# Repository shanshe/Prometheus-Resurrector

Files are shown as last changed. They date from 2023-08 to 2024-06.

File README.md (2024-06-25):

# Prometheus-Resurrector (a.k.a. PrometheusX)

This is a contribution to the project <a href="http://www.e3b.de/prometheus/">Prometheus Open Source</a>. (Based on Xilinx CPLDs).

I didn't contact to anyone at E3B. As far as I know, there is only information about this project in the link above.

Why I do this? The altera version of Prometheus works perfectly, but I like VHDL/verilog and Xilinx (now AMD) FPGA/CPLDs. I have jtags for them so I wanted to play for a while...

I don't have any problem to delete this git if this bothers anyone... but I think that the little work I have done here may be useful to someone, even the original author (AFAIK Michael Boehmer mboehmer@e3b.de).

I have done the following:

 * KiCAD Schematic and PCB.

    I exported gerbers from Eagle PCB project (available at the link <a href="http://www.e3b.de/prometheus/">Prometheus Open Source</a>).
    Then gerbers were imported to a kicad Project.
    I did some modifications as I saw differences between original Prometheus schematics and the new one. Be careful because I did what I thought it was correct. Maybe there are some mistakes. Please, if you think that something is wrong, please open an Issue.

 * Corrected some little issues in the CPLDs firmware.

    The author of this project made a fantastic job, as all the work was made based on simulations only.

    1.- I have corrected the /FCS latch, because in my system, the Prometheus didn't pass autoconfig phase.

    2.- Comparing original prometheus firmware, and the new one, I saw a byteswap in two multiplexers.

    3.- There were some bit swap in the IO (found because voodoo 3 card didn't want to show video signal).

    4.- And finally, reworked the equations of the inputs in the arbiter state machine (SLOT1 X301 didn't work with PPC boards).

    Only a few little mistakes, from a huge project that was only at simulation phase... This was a great engineer job!!!

## Project State

As far as I know, with this board and firmware, you will have a Prometheus board with FireStorm firmware (DMA, PCI-PCI brigdes).

What we need now: drivers!!! For example:

<a href="https://github.com/Sakura-IT/Prometheus.git">https://github.com/Sakura-IT/Prometheus.git</a>

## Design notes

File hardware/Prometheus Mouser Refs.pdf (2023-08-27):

Designator | Footprint | Quantity | Designation | Mouser Ref
R11,R21,R10,R15,R8,R28,R31,R41,R14,R3,R4, R18,R7,R16,R23,R2,R22,R30,R20,R17,R9, R24,R6,R42,R29,R12,R13,R25,R5,R19 | R_0805_2012Metric_Pad1.20x1.40mm_HandSolder | 30 | 1k0 | 603-RT0805FRE101KL
C7,C207,C206,C6,C4,C9,C1,C209,C204,C203, C202,C201,C3,C230,C5,C208,C10,C205,C2,C8,C200,C220 | C_0402_1005Metric_Pad0.74x0.62mm_HandSolder | 22 | 100nF | 581-04025C104KAT4A
C303,C308,C311,C305,C307,C300,C302,C304,C306,C301 | CP_Radial_D6.3mm_P2.50mm | 10 | 100uF | 661-ESMG250ELL101MF
VR100 | TO-252-2 | 1 | AP1117-ADJ | 511-LD1117ADT33-TR
R1 | R_0402_1005Metric_Pad0.72x0.64mm_HandSolder | 1 | 4k7 | 603-RT0402FRE074K7L
X303,X301,X300,X302 | PCI | 4 | Bus_PCI_32bit_5V | 571-5145154-8
R300 | R_1206_3216Metric_Pad1.30x1.75mm_HandSolder | 1 | 2k0 | 708-RMCF1206FT2K00
R43,R44,R46,R45 | R_0805_2012Metric_Pad1.20x1.40mm_HandSolder | 4 | 10k0 | 603-RC0805FR-0710KL
RA202 | R_Array_Convex_4x0612 | 1 | R_Pack04 | 652-CAY16-102J4LF
Q203 | Oscillator_SMD_Fordahl_DFAS15-4Pin_5.0x3.2mm | 1 | 33MHz | 815-SFL133000MHZLRST
R209 | R_0805_2012Metric_Pad1.20x1.40mm_HandSolder | 1 | FerriteBead_Small | 791-WLBD2012HCU600TH
VR300 | DCDC | 1 | ~ | 595-PTH12000WAD
R26 | R_0805_2012Metric_Pad1.20x1.40mm_HandSolder | 1 | 3k3 | 603-RT0805FRE133K3L
C309,C310 | C_1206_3216Metric_Pad1.33x1.80mm_HandSolder | 2 | 100nF | C1206C104K5RAC7210
CON300 | TE-350211-MATE-N-LCK-RightAngle | 1 | Conn_01x04_Pin | 571-16417371
C12,C11 | C_1210_3225Metric_Pad1.33x2.70mm_HandSolder | 2 | 10uF Tantalum | 581-TAJB106K025RNJ
IC201H1,IC200L1 | TQFP-144_20x20mm_P0.5mm | 2 | XC95144XL-TQ144 | 217-5144XL-10TQG144C
R27 | R_0805_2012Metric_Pad1.20x1.40mm_HandSolder | 1 | 4k7 | RC0805FR-074K7L
R202 | R_0805_2012Metric_Pad1.20x1.40mm_HandSolder | 1 | 15R | RC0805FR-0715RL

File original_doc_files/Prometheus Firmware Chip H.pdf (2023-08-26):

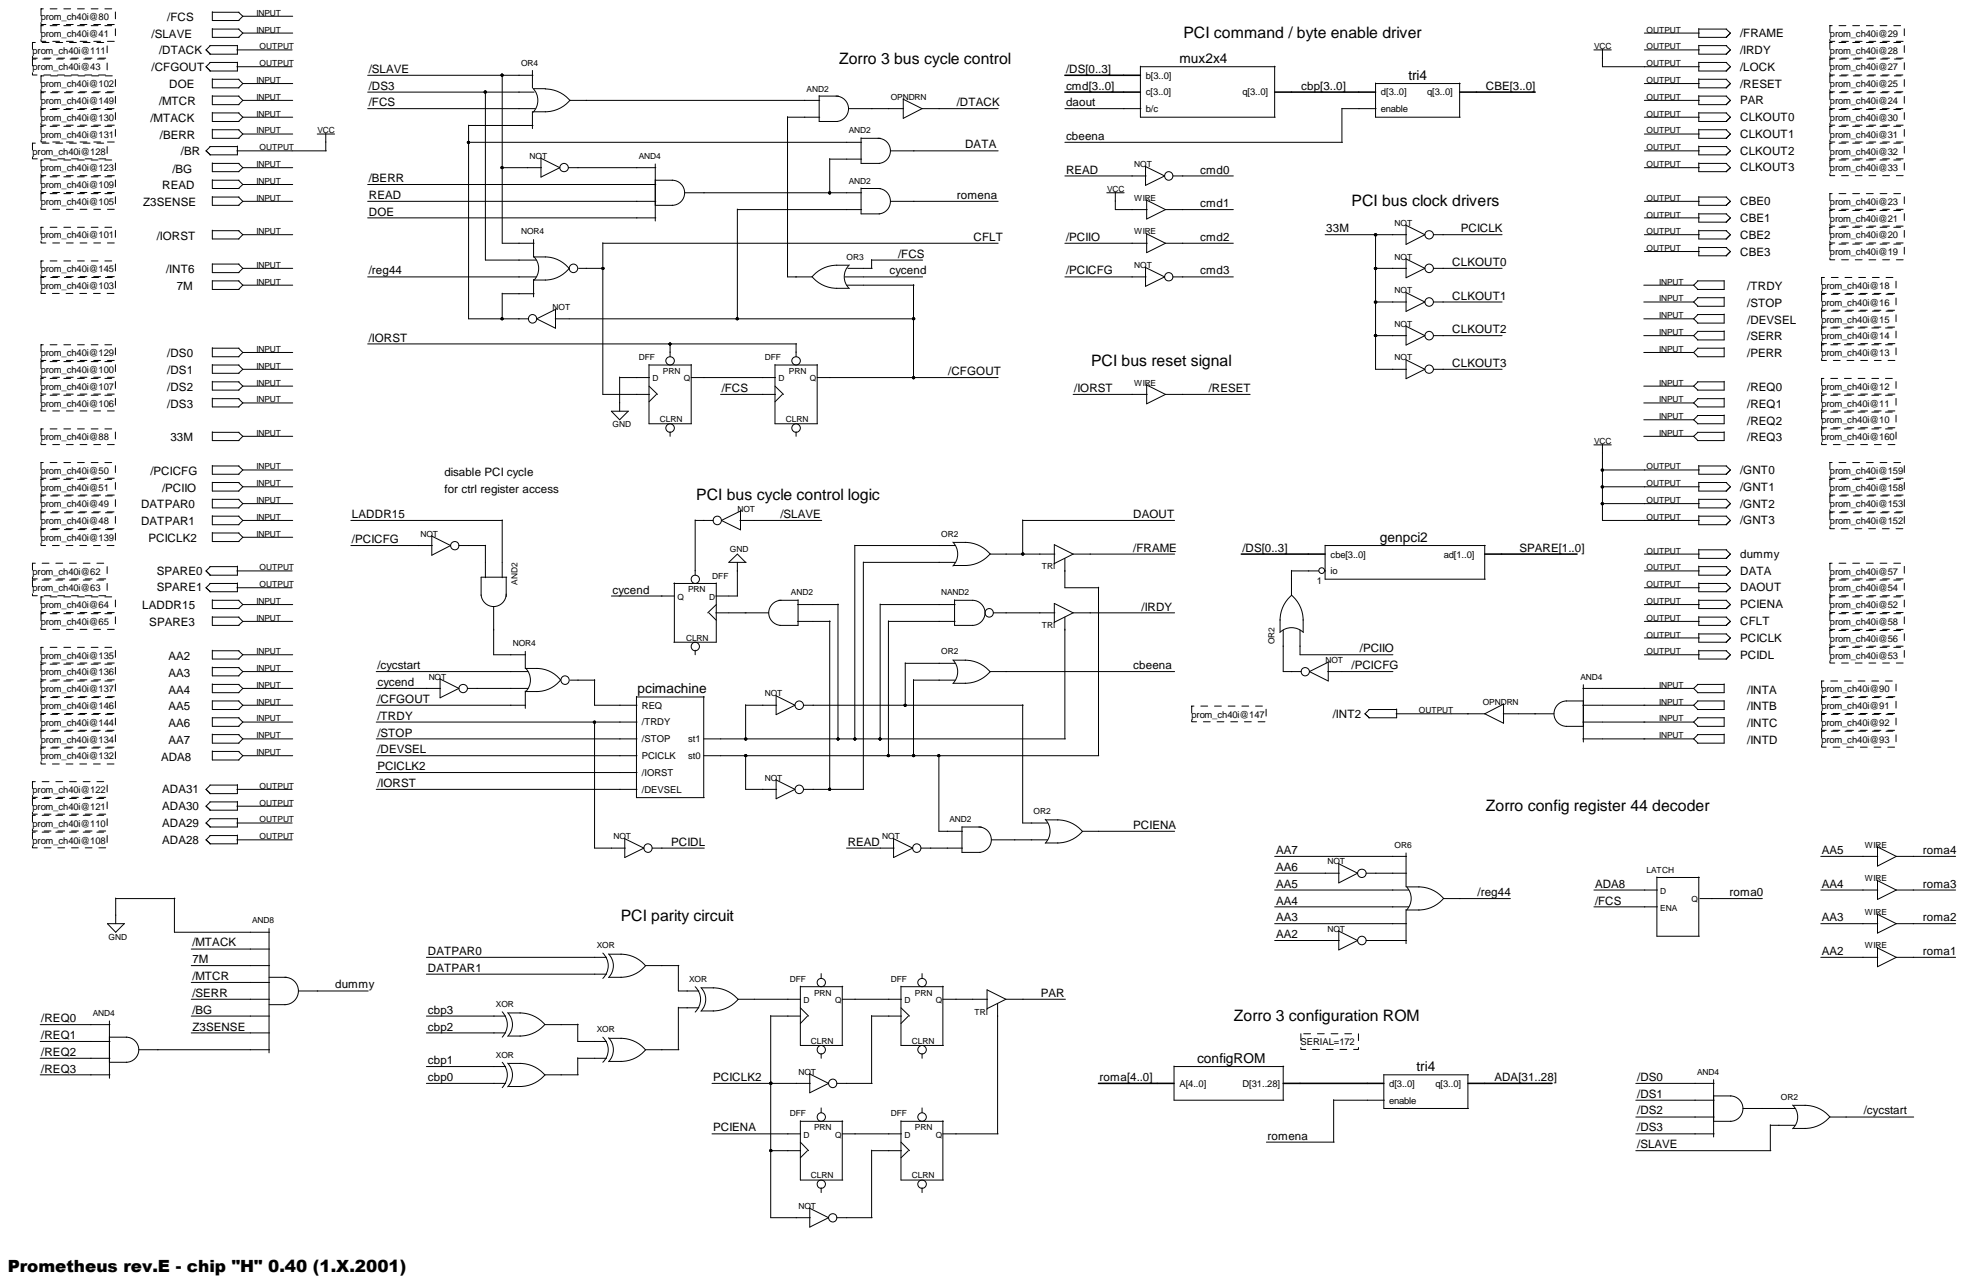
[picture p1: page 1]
/REQ1; prom_ch40i@11 INPUT; /INTD; prom_ch40i@93 INPUT; /INTC; prom_ch40i@92 INPUT; /INTB; prom_ch40i@91 INPUT; /INTA; prom_ch40i@90 INPUT; prom_ch40i@130; /MTACK; INPUT; prom_ch40i@49; DATPAR0; prom_ch40i@132; ADA8; prom_ch40i@134; prom_ch40i@144; prom_ch40i@146; prom_ch40i@137; prom_ch40i@136; prom_ch40i@135; prom_ch40i@65; SPARE3; prom_ch40i@64; LADDR15; prom_ch40i@139; PCICLK2; prom_ch40i@102; DOE; prom_ch40i@48; DATPAR1; prom_ch40i@51; /PCIIO; prom_ch40i@50; /PCICFG; prom_ch40i@41; /SLAVE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

PCI command / byte enable driver
mux2x4

Zorro 3 bus cycle control

PCI bus clock drivers

PCI bus reset signal

disable PCI cycle
for ctrl register access

PCI bus cycle control logic

Zorro config register 44 decoder

PCI parity circuit

Zorro 3 configuration ROM

Prometheus rev.E - chip "H" 0.40 (1.X.2001)

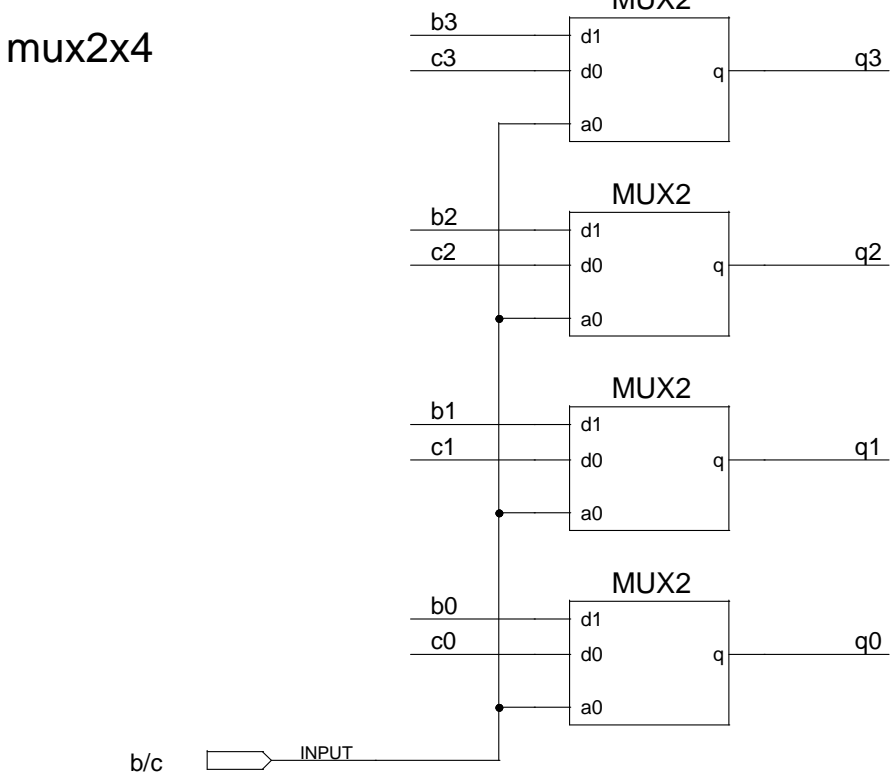
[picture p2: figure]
mux2x4; MUX2; INPUT

### MUX2

c[3..0] | INPUT
b[3..0] | INPUT | q[3..0] OUTPUT

b[3..0]

c[3..0]

q[3..0]

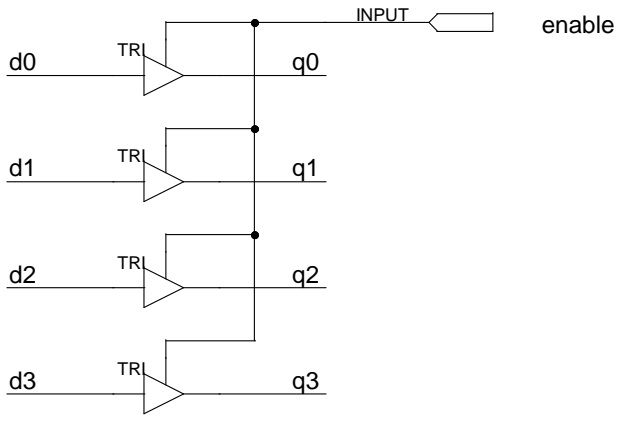
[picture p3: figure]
TRI; enable INPUT

# tri4

d[3..0] | INPUT
q[3..0] d[3..0] | q[3..0] | OUTPUT

SUBDESIGN genpci2
(
cbe[3..0], io : INPUT;
ad[1..0] : OUTPUT;
)

BEGIN
TABLE
cbe[3..0], io => ad1, ad0;
B"0000" , 1 => | 0, | 0;
B"0001" , 1 => | 0, | 1;
B"0010" , 1 => | 0, | 0;
B"0011" , 1 => | 1, | 0;
B"0100" , 1 => | 0, | 0;
B"0101" , 1 => | 0, | 1;
B"0110" , 1 => | 0, | 0;
B"0111" , 1 => | 1, | 1;
B"1000" , 1 => | 0, | 0;
B"1001" , 1 => | 0, | 1;
B"1010" , 1 => | 0, | 0;
B"1011" , 1 => | 1, | 0;
B"1100" , 1 => | 0, | 0;
B"1101" , 1 => | 0, | 1;
B"1110" , 1 => | 0, | 0;
B"1111" , 1 => | 0, | 0;
B"xxxx" , 0 => | 0, | 0;
END TABLE;
END;

### pcimachine2

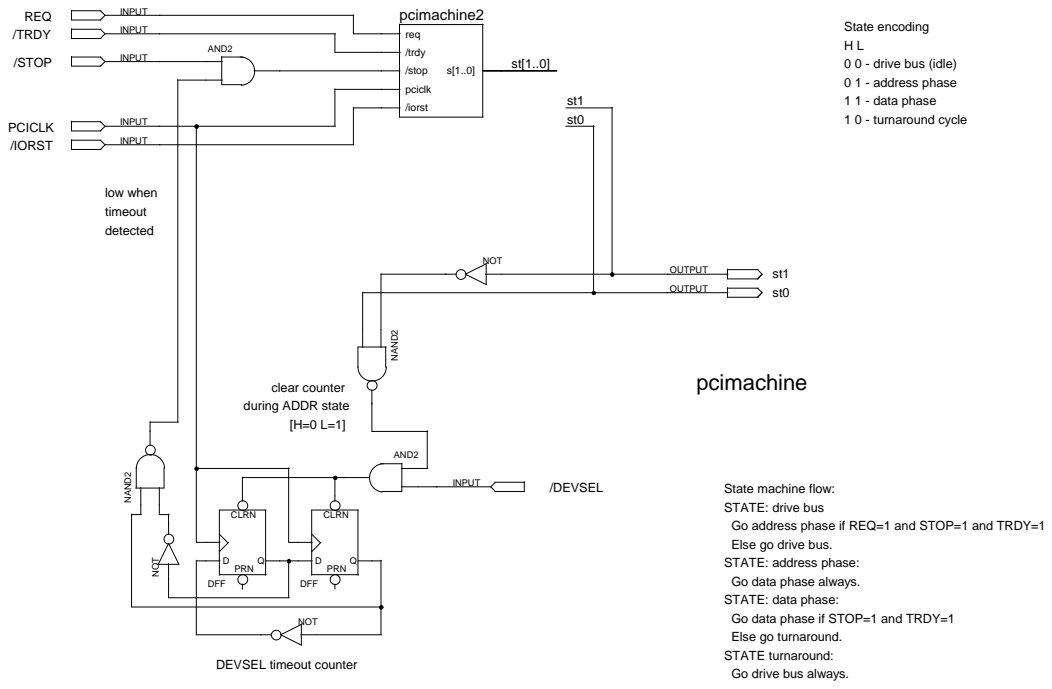
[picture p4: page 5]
detected; low when timeout; pcimachine; DFF; CLRN; PRN; PCICLK; INPUT; /IORST; /DEVSEL INPUT; /STOP; /TRDY; REQ; st0 OUTPUT; st1 OUTPUT; NOT; AND2; NAND2; req /trdy /stop pciclk /iorst

State encoding
0 0 - drive bus (idle)
0 1 - address phase
1 1 - data phase
1 0 - turnaround cycle

clear counter
during ADDR state

State machine flow:
STATE: drive bus
Go address phase if REQ=1 and STOP=1 and TRDY=1
Else go drive bus.
STATE: address phase:
Go data phase always.
STATE: data phase:
Go data phase if STOP=1 and TRDY=1
Else go turnaround.
STATE turnaround:
Go drive bus always.

DEVSEL timeout counter

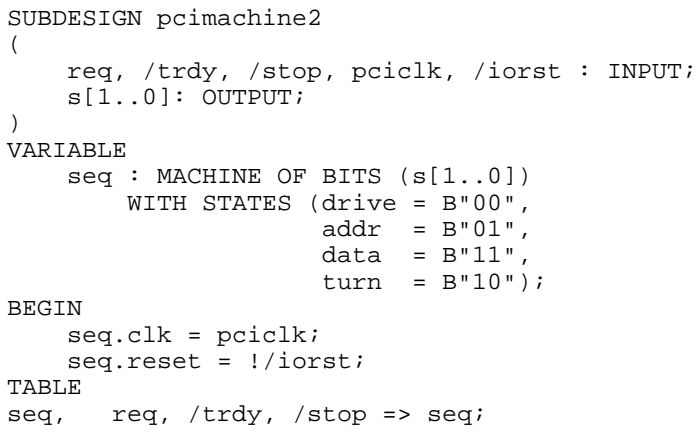
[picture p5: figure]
SUBDESIGN pcimachine2 (; s[1..0]: OUTPUT;; ) VARIABLE seq : MACHINE OF BITS (s[1..0]) WITH STATES (drive = B"00", addr = B"01", data = B"11", turn = B"10");; BEGIN seq.clk = pciclk; seq.reset = !/iorst; TABLE; seq,; req, /trdy, /stop => seq;

req, /trdy, /stop, pciclk, /iorst : INPUT;

drive, | 0, | X, | X => drive;
drive, | 1, | 0, | X => drive;
drive, | 1, | 1, | 0 => drive;
drive, | 1, | 1, | 1 => addr;
addr, | X, | X, | X => data;
data, | X, | 0, | X => turn;
data, | X, | 1, | 0 => turn;
data, | X, | 1, | 1 => data;
turn, | X, | X, | X => drive;
END TABLE;
END;

PARAMETERS
(
SERIAL
);

CONSTANT S0R = ((SERIAL & H"F0000000") DIV H"10000000") XOR H"F"; CONSTANT S1R = ((SERIAL & H"0F000000") DIV H"01000000") XOR H"F"; CONSTANT S2R = ((SERIAL & H"00F00000") DIV H"00100000") XOR H"F"; CONSTANT S3R = ((SERIAL & H"000F0000") DIV H"00010000") XOR H"F"; CONSTANT S4R = ((SERIAL & H"0000F000") DIV H"00001000") XOR H"F"; CONSTANT S5R = ((SERIAL & H"00000F00") DIV H"00000100") XOR H"F";
CONSTANT S6R = ((SERIAL & H"000000F0") DIV H"00000010") XOR H"F";
CONSTANT S7R = ((SERIAL & H"0000000F") DIV H"00000001") XOR H"F";

CONSTANT MANUFACTURER = H"AD47"; % Amiga Inc. hardware developer number %

CONSTANT M0R = ((MANUFACTURER & H"F000") DIV H"1000") XOR H"F";
CONSTANT M1R = ((MANUFACTURER & H"0F00") DIV H"0100") XOR H"F";
CONSTANT M2R = ((MANUFACTURER & H"00F0") DIV H"0010") XOR H"F";
CONSTANT M3R = ((MANUFACTURER & H"000F") DIV H"0001") XOR H"F";
CONSTANT DEVTYPE = 1; | % device type %

CONSTANT D0R = ((DEVTYPE & H"F0") DIV H"10") XOR H"F";
CONSTANT D1R = ((DEVTYPE & H"0F") DIV H"01") XOR H"F";
CONSTANT ROMVEC = H"0000"; | % ROM offset (currently unused) %

CONSTANT R0R = ((ROMVEC & H"F000") DIV H"1000") XOR H"F";
CONSTANT R1R = ((ROMVEC & H"0F00") DIV H"0100") XOR H"F";
CONSTANT R2R = ((ROMVEC & H"00F0") DIV H"0010") XOR H"F";
CONSTANT R3R = ((ROMVEC & H"000F") DIV H"0001") XOR H"F";

SUBDESIGN ConfigROM
(
A[4..0] : INPUT;
D[31..28] : OUTPUT;
)
BEGIN
CASE A[] IS
WHEN 0 => D[] = B"1000"; % $000 - Z3 type, no autolink RAM, no boot ROM %
WHEN 1 => D[] = B"0101"; % $101 - single dev. board, 512 MB size | %

% device number (see constant above), register $004 %

WHEN 2 => D[] = D0R;
WHEN 3 => D[] = D1R;
WHEN 4 => D[] = B"1100"; % $008 - I/O dev., not shutupable, Z3 size | %
WHEN 5 => D[] = B"1111"; % $108 - Logical size matches physical size | %

WHEN 6 => D[] = B"1111"; % $00C - Reserved | %
WHEN 7 => D[] = B"1111"; % $10C - Reserved | %

% manufacturer number (see constant above), registers $010 and $014 %

WHEN 8 => D[] = M0R;
WHEN 9 => D[] = M1R;
WHEN 10 => D[] = M2R;
WHEN 11 => D[] = M3R;

% serial number (see constant above), registers $018 to $024 %

WHEN 12 => D[] = S0R;
WHEN 13 => D[] = S1R;
WHEN 14 => D[] = S2R;
WHEN 15 => D[] = S3R;
WHEN 16 => D[] = S4R;
WHEN 17 => D[] = S5R;
WHEN 18 => D[] = S6R;
WHEN 19 => D[] = S7R;

% ROM vector (see constant above), registers $028 and $02C %

WHEN 20 => D[] = R0R;
WHEN 21 => D[] = R1R;
WHEN 22 => D[] = R2R;
WHEN 23 => D[] = R3R;

% others reserved %

WHEN OTHERS => D[] = B"1111"; END CASE;
END;

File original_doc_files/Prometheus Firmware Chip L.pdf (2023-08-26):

Zorro 3 address latch | Zorro 3 address gate (512 MB) | Address decoder | PCI space decoder

## latch8

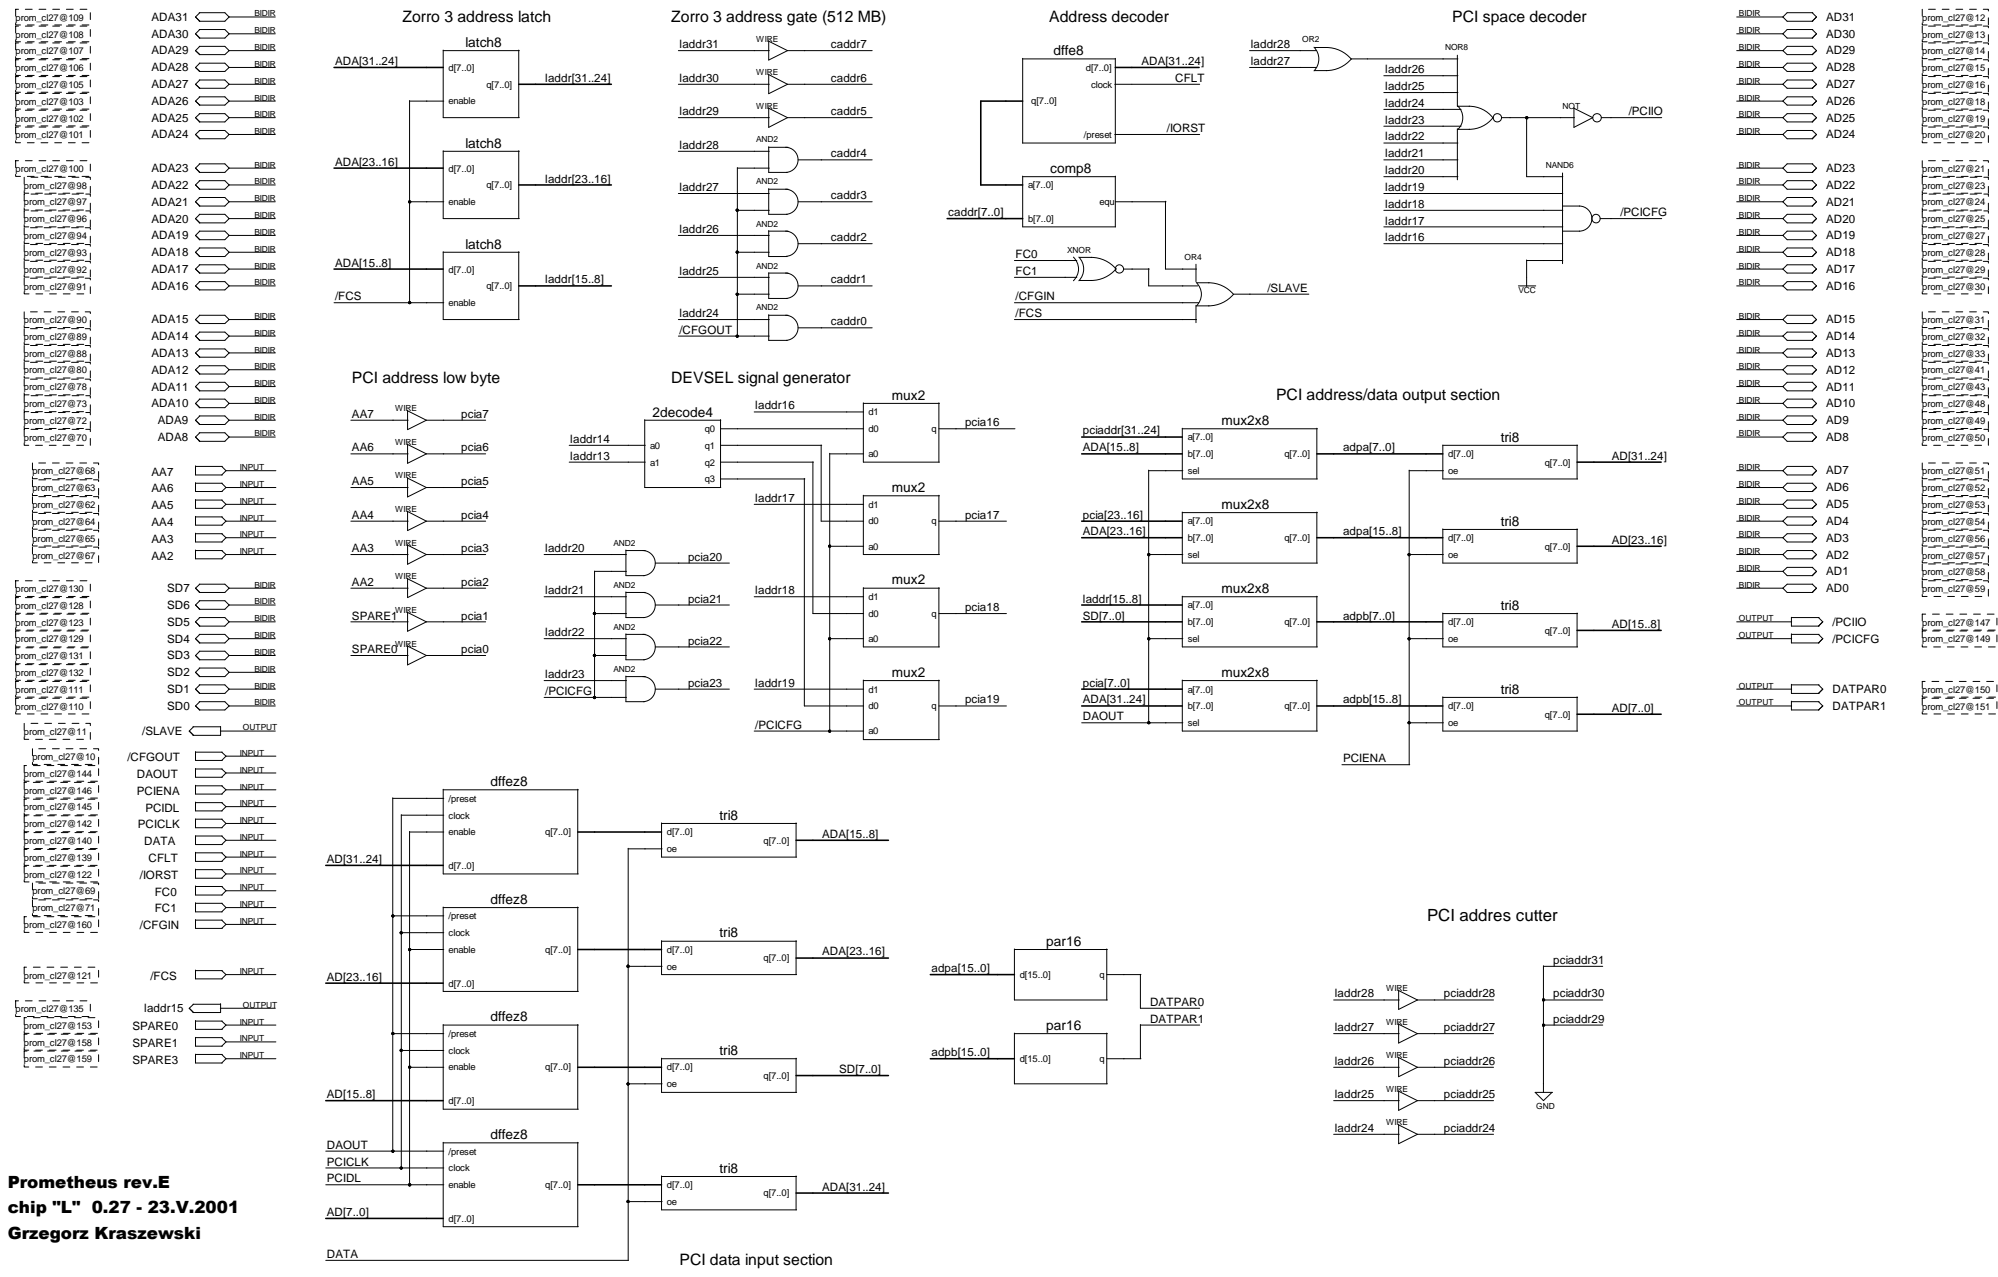
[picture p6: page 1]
PCI address low byte; DEVSEL signal generator; Prometheus rev.E; chip "L" 0.27 - 23.V.2001; Grzegorz Kraszewski; prom_cl27@109; ADA31; BIDIR; prom_cl27@59 BIDIR; prom_cl27@57 BIDIR; prom_cl27@58 BIDIR; prom_cl27@56 BIDIR; prom_cl27@54 BIDIR; prom_cl27@52 BIDIR; prom_cl27@53 BIDIR; prom_cl27@51 BIDIR; prom_cl27@49 BIDIR; prom_cl27@50 BIDIR; prom_cl27@43 BIDIR; prom_cl27@48 BIDIR; prom_cl27@33 BIDIR; prom_cl27@41 BIDIR; prom_cl27@31 BIDIR; prom_cl27@32 BIDIR; prom_cl27@30 BIDIR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

PCI address/data output section

PCI addres cutter

PCI data input section

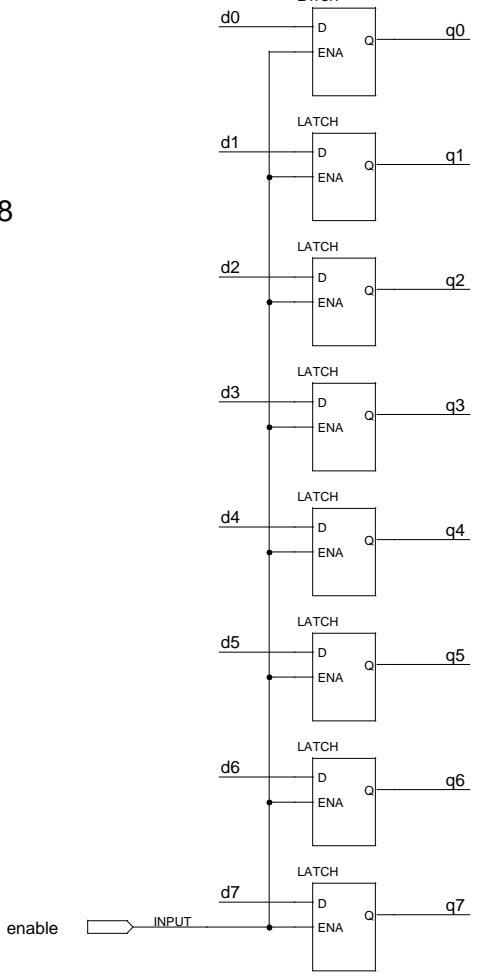
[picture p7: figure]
ENA; LATCH; enable; INPUT

# latch8

## LATCH

d[7..0] | INPUT | q[7..0] OUTPUT
d[7..0] | q[7..0]

# dffe8

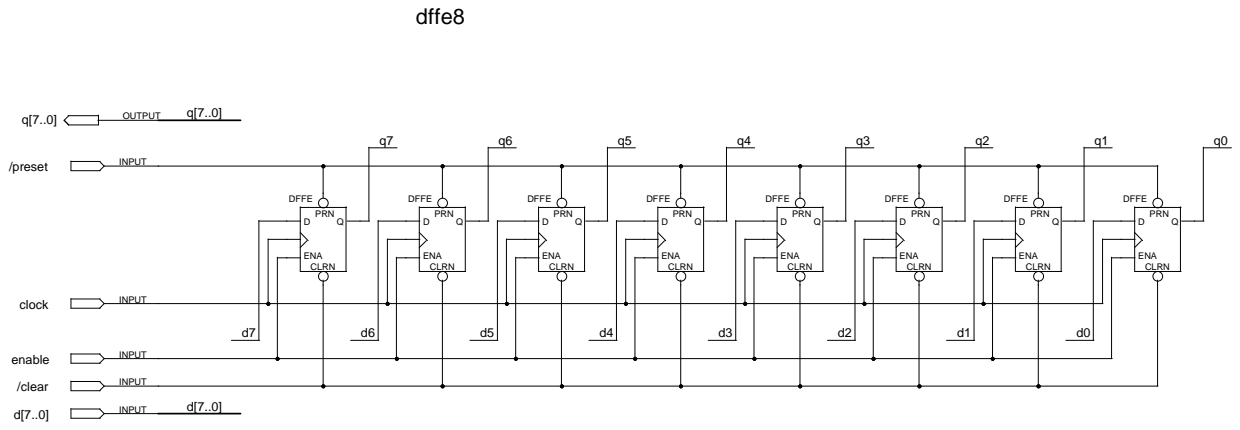
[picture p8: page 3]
enable; INPUT; /clear; clock; /preset; OUTPUT; DFFE; ENA CLRN; PRN

# comp8

# XOR

a[7..0] | INPUT
b[7..0] | INPUT

a7

a[7..0]

b[7..0]

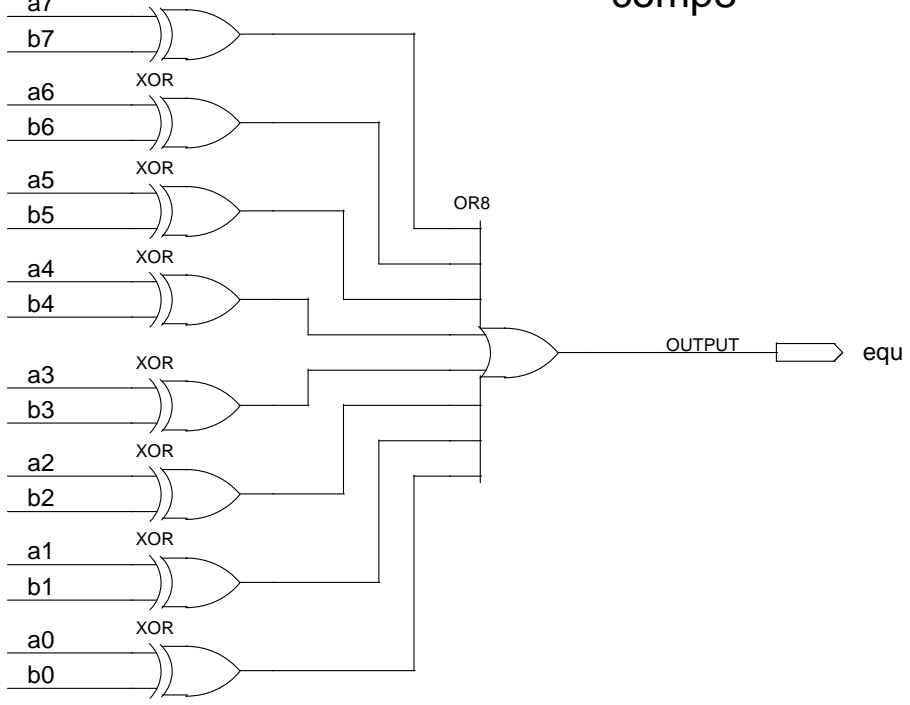
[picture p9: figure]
XOR; equ OUTPUT

# 2decode4

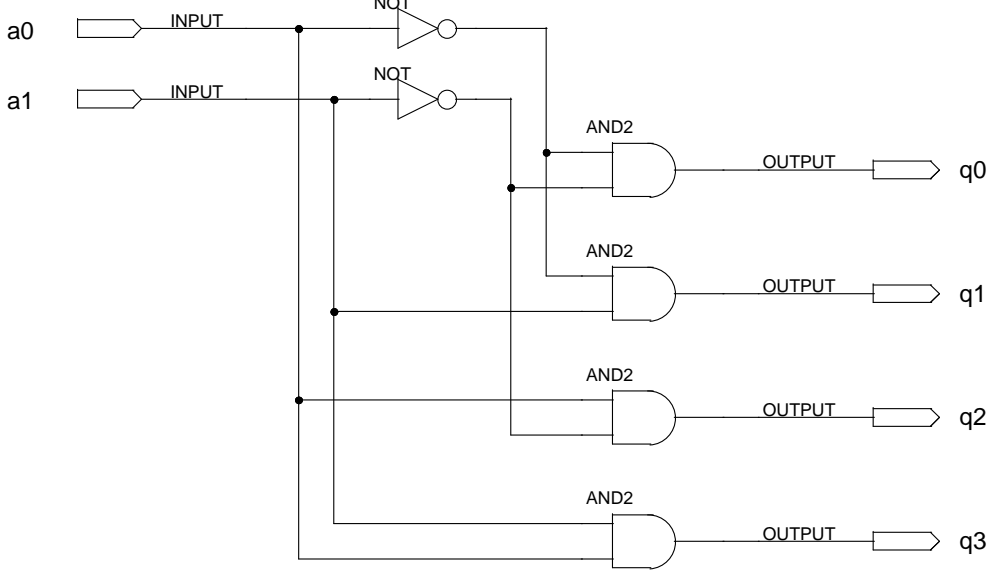
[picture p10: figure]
AND2; NOT; INPUT; q0 OUTPUT; q3 OUTPUT; q2 OUTPUT; q1 OUTPUT

# NOT

# mux2

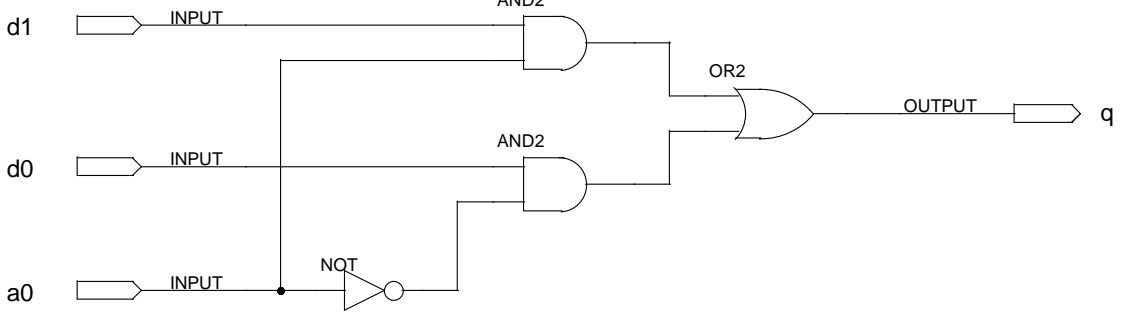
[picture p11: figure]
AND2; NOT; INPUT; q OUTPUT

# AND2

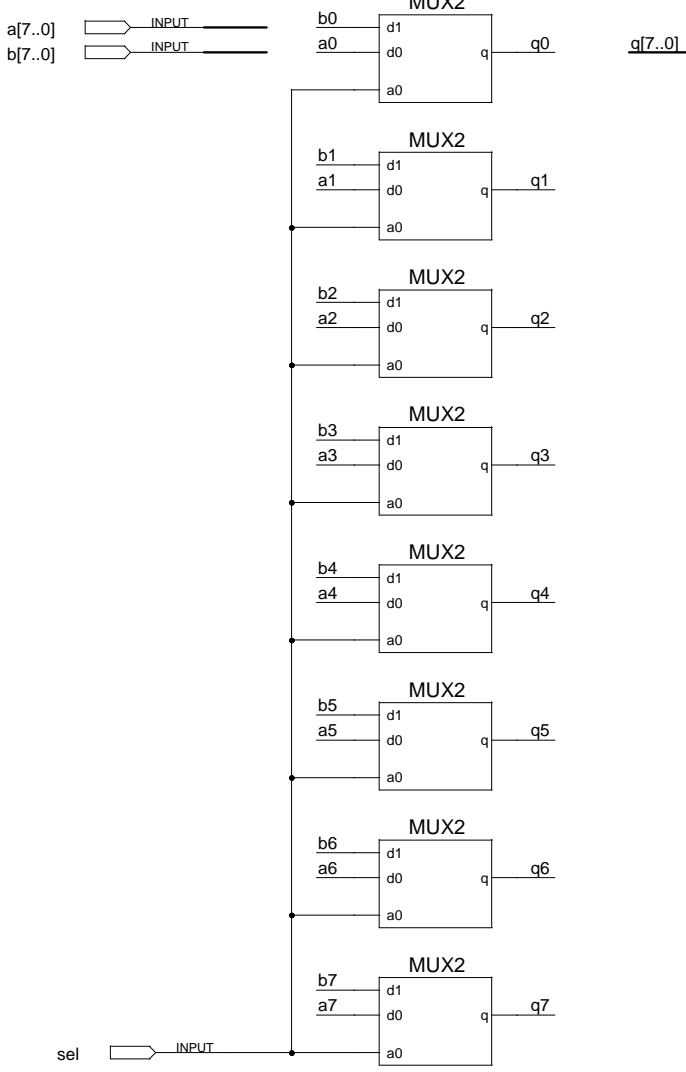
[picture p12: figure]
MUX2; INPUT; sel

# mux2x8

# MUX2

# q[7..0] OUTPUT

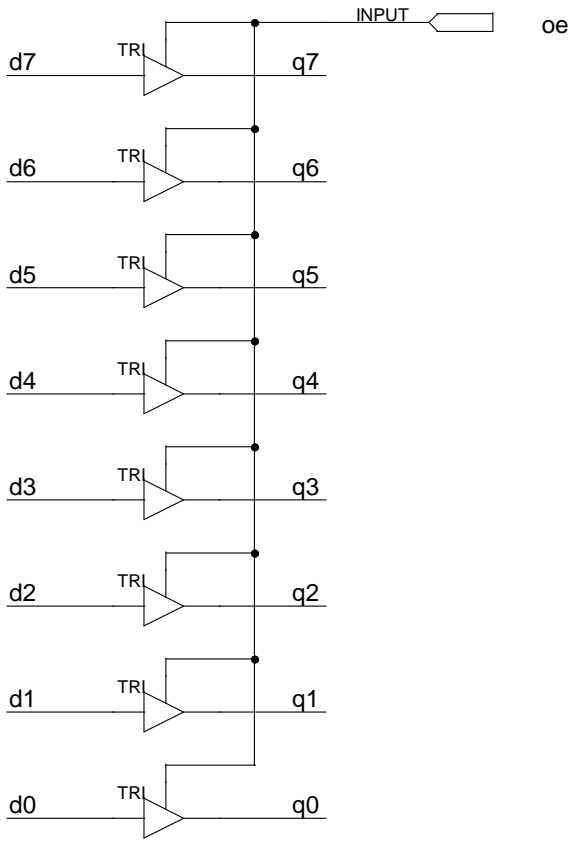
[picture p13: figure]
TRI; oe INPUT

# tri8

d[7..0] | INPUT
q[7..0] d[7..0] | q[7..0] | OUTPUT

# dffez8

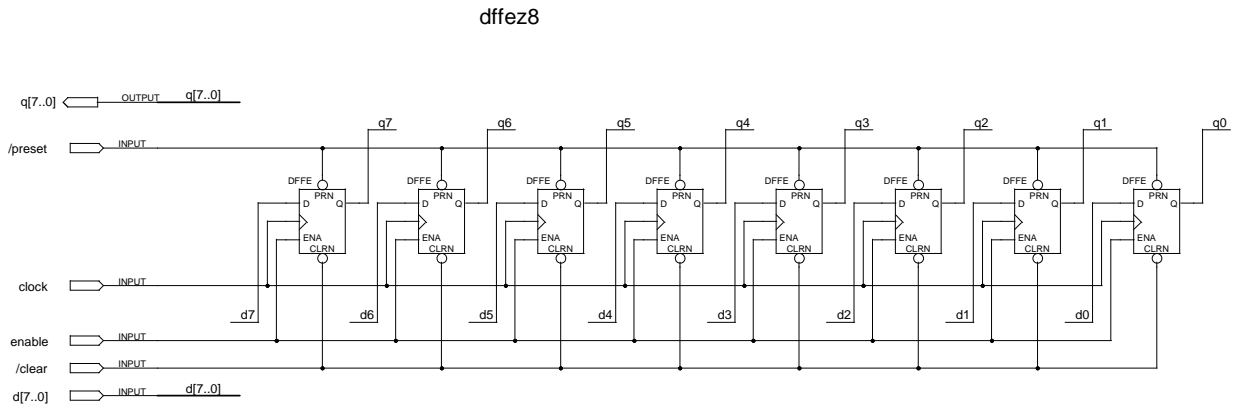
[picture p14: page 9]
INPUT; /clear; enable; clock; /preset; OUTPUT; DFFE; ENA CLRN; PRN

# par16

# XOR

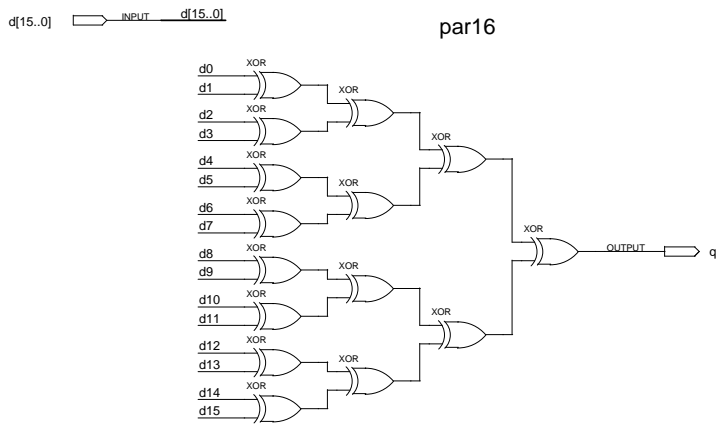
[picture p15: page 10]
XOR; q OUTPUT; INPUT

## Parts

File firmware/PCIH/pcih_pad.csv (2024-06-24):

Release 8.1i - Fit P.20131013
Copyright(c) 1995-2003 Xilinx Inc. All rights reserved
6-24-2024 8:03PM
NOTE: This file is designed to be imported into a spreadsheet program
such as Microsoft Excel for viewing | printing and sorting. The comma ' | '
character is used as the data field separator.
This file is also designed to support parsing.
Input file: pcih.ngd
output file: pcih_pad.csv
Part type: xc95144xl
Speed grade: -10
Package: tq144
Pinout by Pin Number:
----- | ----- | ----- | ----- | ----- | ----- | ----- | ----- | ----- | -----
Pin Number | Signal Name | Pin Usage | Pin Name | Direction | IO Standard | IO Bank Number | {blank} | Slew Rate | Termination | {blank} | Voltage | Constraint
P1 | VCC |  | VCCIO
P2 | TIE |  | I/O/GTS3
P3 | TIE |  | I/O/GTS4
P4 | TIE |  | I/O
P5 | TIE |  | I/O/GTS1
P6 | TIE |  | I/O/GTS2
P7 | TIE |  | I/O
P8 | VCC |  | VCCINT
P9 | Z_AA<5> | I | I/O | INPUT
P10 | TIE |  | I/O
P11 | Z_AA<6> | I | I/O | INPUT
P12 | Z_AA<4> | I | I/O | INPUT
P13 | Z_AA<3> | I | I/O | INPUT
P14 | TIE |  | I/O
P15 | Z_AA<2> | I | I/O | INPUT
P16 | Z_AA<7> | I | I/O | INPUT
P17 | TIE |  | I/O
P18 | GND |  | GND
P19 | TIE |  | I/O
P20 | Z_NBERR | I | I/O | INPUT
P21 | Z_READ | I | I/O | INPUT
P22 | Z_ADA<29> | O | I/O | OUTPUT
P23 | Z_NDTACK | O | I/O | OUTPUT
P24 | Z_ADA<30> | I/O | I/O | BIDIR
P25 | Z_ADA<31> | I/O | I/O | BIDIR
P26 | Z_NDS<0> | I | I/O | INPUT
P27 | Z_ADA<28> | O | I/O | OUTPUT
P28 | Z_NDS<2> | I | I/O | INPUT
P29 | GND |  | GND
P30 | I_33M | I | I/O/GCK1 | INPUT
P31 | I_PCICLK | O | I/O | OUTPUT
P32 | I_PCICLK2 | GCK | I/O/GCK2
P33 | Z_NDS<3> | I | I/O | INPUT
P34 | TIE |  | I/O
P35 | Z_DOE | I | I/O | INPUT
P36 | GND |  | GND
P37 | VCC |  | VCCIO
P38 | Z_NFCS | GCK/I | I/O/GCK3
P39 | Z_NDS<1> | I | I/O | INPUT
P40 | I_ACC<1> | I | I/O | INPUT
P41 | I_ACC<0> | I | I/O | INPUT
P42 | VCC |  | VCCINT
P43 | I_DATPAR<1> | I | I/O | INPUT
P44 | I_DATPAR<0> | I | I/O | INPUT
P45 | I_DAOUT | O | I/O | OUTPUT
P46 | I_PCIENA | O | I/O | OUTPUT
P47 | GND |  | GND
P48 | I_PCIDL | O | I/O | OUTPUT
P49 | I_DATA | O | I/O | OUTPUT
P50 | I_CFLT | O | I/O | OUTPUT
P51 | I_PLA<1> | O | I/O | OUTPUT
P52 | I_PLA<0> | O | I/O | OUTPUT
P53 | I_ZLA | I | I/O | INPUT
P54 | I_ZMA | I | I/O | INPUT
P55 | VCC |  | VCCIO
P56 | TIE |  | I/O
P57 | TIE |  | I/O
P58 | TIE |  | I/O
P59 | TIE |  | I/O
P60 | TIE |  | I/O
P61 | TIE |  | I/O
P62 | GND |  | GND
P63 | TDI |  | TDI
P64 | TIE |  | I/O
P65 | TMS |  | TMS
P66 | TIE |  | I/O
P67 | TCK |  | TCK
P68 | I_NINT6 | O | I/O | OUTPUT
P69 | I_NINT2 | O | I/O | OUTPUT
P70 | Z_NCFGOUT | O | I/O | OUTPUT
P71 | Z_NSLAVE | I | I/O | INPUT
P72 | GND |  | GND
P73 | VCC |  | VCCIO
P74 | P_CBE<1> | I/O | I/O | BIDIR
P75 | TIE |  | I/O
P76 | TIE |  | I/O
P77 | P_NLOCK | O | I/O | OUTPUT
P78 | P_NDEVSEL | I | I/O | INPUT
P79 | P_NIRDY | I/O | I/O | BIDIR
P80 | P_CBE<2> | I/O | I/O | BIDIR
P81 | P_CBE<3> | I/O | I/O | BIDIR
P82 | P_NREQ<0> | I | I/O | INPUT
P83 | P_NGNT<1> | O | I/O | OUTPUT
P84 | VCC |  | VCCINT
P85 | P_NREQ<1> | I | I/O | INPUT
P86 | P_NGNT<0> | O | I/O | OUTPUT
P87 | P_CLKOUT<0> | O | I/O | OUTPUT
P88 | P_CLKOUT<1> | O | I/O | OUTPUT
P89 | GND |  | GND
P90 | GND |  | GND
P91 | P_NINTC | I | I/O | INPUT
P92 | P_NINTD | I | I/O | INPUT
P93 | P_NINTA | I | I/O | INPUT
P94 | P_NINTB | I | I/O | INPUT
P95 | P_NRESET | O | I/O | OUTPUT
P96 | P_CLKOUT<3> | O | I/O | OUTPUT
P97 | P_NGNT<3> | O | I/O | OUTPUT
P98 | P_NREQ<3> | I | I/O | INPUT
P99 | GND |  | GND
P100 | P_NGNT<2> | O | I/O | OUTPUT
P101 | P_CLKOUT<2> | O | I/O | OUTPUT
P102 | P_NREQ<2> | I | I/O | INPUT
P103 | P_NFRAME | I/O | I/O | BIDIR
P104 | P_NTRDY | I | I/O | INPUT
P105 | P_NSTOP | I | I/O | INPUT
P106 | P_PAR | O | I/O | OUTPUT
P107 | P_CBE<0> | I/O | I/O | BIDIR
P108 | GND |  | GND
P109 | VCC |  | VCCIO
P110 | TIE |  | I/O
P111 | TIE |  | I/O
P112 | TIE |  | I/O
P113 | TIE |  | I/O
P114 | GND |  | GND
P115 | TIE |  | I/O
P116 | DEBUG<0> | O | I/O | OUTPUT
P117 | DEBUG<1> | O | I/O | OUTPUT
P118 | DEBUG<2> | O | I/O | OUTPUT
P119 | DEBUG<3> | O | I/O | OUTPUT
P120 | DEBUG<4> | O | I/O | OUTPUT
P121 | DEBUG<5> | O | I/O | OUTPUT
P122 | TDO |  | TDO
P123 | GND |  | GND
P124 | TIE |  | I/O
P125 | TIE |  | I/O
P126 | TIE |  | I/O
P127 | VCC |  | VCCIO
P128 | DEBUG<6> | O | I/O | OUTPUT
P129 | DEBUG<7> | O | I/O | OUTPUT
P130 | DEBUG<8> | O | I/O | OUTPUT
P131 | DEBUG<9> | O | I/O | OUTPUT
P132 | DEBUG<10> | O | I/O | OUTPUT
P133 | DEBUG<11> | O | I/O | OUTPUT
P134 | DEBUG<12> | O | I/O | OUTPUT
P135 | DEBUG<13> | O | I/O | OUTPUT
P136 | DEBUG<14> | O | I/O | OUTPUT
P137 | DEBUG<15> | O | I/O | OUTPUT
P138 | TIE |  | I/O
P139 | TIE |  | I/O
P140 | TIE |  | I/O
P141 | VCC |  | VCCINT
P142 | TIE |  | I/O
P143 | Z_NIORST | GSR/I | I/O/GSR
P144 | GND |  | GND
To preserve the pinout above for future design iterations in
Project Navigator simply execute the (Lock Pins) process
located under the (Implement Design) process in a toolbox named
(Optional Implementation Tools) or invoke PIN2UCF from the
command line. The location constraints will be written into your
specified UCF file

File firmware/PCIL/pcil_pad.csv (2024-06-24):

Release 8.1i - Fit P.20131013
Copyright(c) 1995-2003 Xilinx Inc. All rights reserved
6-24-2024 7:58PM
NOTE: This file is designed to be imported into a spreadsheet program
such as Microsoft Excel for viewing | printing and sorting. The comma ' | '
character is used as the data field separator.
This file is also designed to support parsing.
Input file: pcil.ngd
output file: pcil_pad.csv
Part type: xc95144xl
Speed grade: -10
Package: tq144
Pinout by Pin Number:
----- | ----- | ----- | ----- | ----- | ----- | ----- | ----- | ----- | -----
Pin Number | Signal Name | Pin Usage | Pin Name | Direction | IO Standard | IO Bank Number | {blank} | Slew Rate | Termination | {blank} | Voltage | Constraint
P1 | VCC |  | VCCIO
P2 | TIE |  | I/O/GTS3
P3 | TIE |  | I/O/GTS4
P4 | Z_SD<5> | I/O | I/O | BIDIR
P5 | Z_SD<6> | I/O | I/O/GTS1 | BIDIR
P6 | Z_SD<4> | I/O | I/O/GTS2 | BIDIR
P7 | Z_SD<7> | I/O | I/O | BIDIR
P8 | VCC |  | VCCINT
P9 | Z_SD<3> | I/O | I/O | BIDIR
P10 | Z_ADA<24> | I/O | I/O | BIDIR
P11 | Z_SD<2> | I/O | I/O | BIDIR
P12 | Z_ADA<25> | I/O | I/O | BIDIR
P13 | Z_SD<1> | I/O | I/O | BIDIR
P14 | Z_ADA<26> | I/O | I/O | BIDIR
P15 | Z_SD<0> | I/O | I/O | BIDIR
P16 | TIE |  | I/O
P17 | Z_ADA<27> | I/O | I/O | BIDIR
P18 | GND |  | GND
P19 | TIE |  | I/O
P20 | Z_ADA<28> | I/O | I/O | BIDIR
P21 | Z_ADA<17> | I/O | I/O | BIDIR
P22 | TIE |  | I/O
P23 | Z_ADA<18> | I/O | I/O | BIDIR
P24 | Z_ADA<19> | I/O | I/O | BIDIR
P25 | Z_ADA<20> | I/O | I/O | BIDIR
P26 | Z_ADA<22> | I/O | I/O | BIDIR
P27 | Z_ADA<21> | I/O | I/O | BIDIR
P28 | Z_ADA<23> | I/O | I/O | BIDIR
P29 | GND |  | GND
P30 | I_PCICLK | GCK | I/O/GCK1
P31 | Z_ADA<31> | I/O | I/O | BIDIR
P32 | Z_ADA<30> | I/O | I/O/GCK2 | BIDIR
P33 | TIE |  | I/O
P34 | Z_ADA<29> | I/O | I/O | BIDIR
P35 | TIE |  | I/O
P36 | GND |  | GND
P37 | VCC |  | VCCIO
P38 | Z_NFCS | GCK/I | I/O/GCK3
P39 | TIE |  | I/O
P40 | Z_ADA<16> | I/O | I/O | BIDIR
P41 | Z_ADA<15> | I/O | I/O | BIDIR
P42 | VCC |  | VCCINT
P43 | Z_ADA<14> | I/O | I/O | BIDIR
P44 | Z_ADA<13> | I/O | I/O | BIDIR
P45 | Z_ADA<12> | I/O | I/O | BIDIR
P46 | Z_ADA<11> | I/O | I/O | BIDIR
P47 | GND |  | GND
P48 | Z_ADA<10> | I/O | I/O | BIDIR
P49 | Z_FC<1> | I | I/O | INPUT
P50 | Z_ADA<9> | I/O | I/O | BIDIR
P51 | Z_FC<0> | I | I/O | INPUT
P52 | Z_ADA<8> | I/O | I/O | BIDIR
P53 | Z_AA<7> | I | I/O | INPUT
P54 | Z_AA<2> | I | I/O | INPUT
P55 | VCC |  | VCCIO
P56 | Z_AA<3> | I | I/O | INPUT
P57 | Z_AA<4> | I | I/O | INPUT
P58 | Z_AA<6> | I | I/O | INPUT
P59 | Z_AA<5> | I | I/O | INPUT
P60 | Z_NCFGIN | I | I/O | INPUT
P61 | Z_NCFGOUT | I | I/O | INPUT
P62 | GND |  | GND
P63 | TDI |  | TDI
P64 | TIE |  | I/O
P65 | TMS |  | TMS
P66 | TIE |  | I/O
P67 | TCK |  | TCK
P68 | Z_NSLAVE | O | I/O | OUTPUT
P69 | Z_NINT6 | O | I/O | OUTPUT
P70 | Z_NINT2 | O | I/O | OUTPUT
P71 | TIE |  | I/O
P72 | GND |  | GND
P73 | VCC |  | VCCIO
P74 | P_AD<7> | I/O | I/O | BIDIR
P75 | P_AD<5> | I/O | I/O | BIDIR
P76 | P_AD<3> | I/O | I/O | BIDIR
P77 | P_AD<1> | I/O | I/O | BIDIR
P78 | P_AD<8> | I/O | I/O | BIDIR
P79 | P_AD<10> | I/O | I/O | BIDIR
P80 | P_AD<12> | I/O | I/O | BIDIR
P81 | P_AD<14> | I/O | I/O | BIDIR
P82 | P_AD<17> | I/O | I/O | BIDIR
P83 | P_AD<19> | I/O | I/O | BIDIR
P84 | VCC |  | VCCINT
P85 | P_AD<21> | I/O | I/O | BIDIR
P86 | P_AD<23> | I/O | I/O | BIDIR
P87 | P_AD<25> | I/O | I/O | BIDIR
P88 | P_AD<27> | I/O | I/O | BIDIR
P89 | GND |  | GND
P90 | GND |  | GND
P91 | P_AD<29> | I/O | I/O | BIDIR
P92 | P_AD<31> | I/O | I/O | BIDIR
P93 | P_AD<30> | I/O | I/O | BIDIR
P94 | P_AD<28> | I/O | I/O | BIDIR
P95 | P_AD<26> | I/O | I/O | BIDIR
P96 | P_AD<24> | I/O | I/O | BIDIR
P97 | P_AD<22> | I/O | I/O | BIDIR
P98 | P_AD<20> | I/O | I/O | BIDIR
P99 | GND |  | GND
P100 | P_AD<18> | I/O | I/O | BIDIR
P101 | P_AD<16> | I/O | I/O | BIDIR
P102 | P_AD<15> | I/O | I/O | BIDIR
P103 | P_AD<13> | I/O | I/O | BIDIR
P104 | P_AD<11> | I/O | I/O | BIDIR
P105 | P_AD<9> | I/O | I/O | BIDIR
P106 | P_AD<6> | I/O | I/O | BIDIR
P107 | P_AD<4> | I/O | I/O | BIDIR
P108 | GND |  | GND
P109 | VCC |  | VCCIO
P110 | P_AD<2> | I/O | I/O | BIDIR
P111 | P_AD<0> | I/O | I/O | BIDIR
P112 | TIE |  | I/O
P113 | TIE |  | I/O
P114 | GND |  | GND
P115 | TIE |  | I/O
P116 | TIE |  | I/O
P117 | TIE |  | I/O
P118 | I_NINT2 | I | I/O | INPUT
P119 | I_NINT6 | I | I/O | INPUT
P120 | TIE |  | I/O
P121 | I_ADD<3> | O | I/O | OUTPUT
P122 | TDO |  | TDO
P123 | GND |  | GND
P124 | I_ADD<2> | O | I/O | OUTPUT
P125 | I_ADD<1> | O | I/O | OUTPUT
P126 | I_ADD<0> | O | I/O | OUTPUT
P127 | VCC |  | VCCIO
P128 | I_ZMA | O | I/O | OUTPUT
P129 | I_ZLA | O | I/O | OUTPUT
P130 | I_PLA<0> | I | I/O | INPUT
P131 | I_PLA<1> | I | I/O | INPUT
P132 | I_CFLT | I | I/O | INPUT
P133 | I_DATA | I | I/O | INPUT
P134 | I_PCIDL | I | I/O | INPUT
P135 | I_PCIENA | I | I/O | INPUT
P136 | I_DAOUT | I | I/O | INPUT
P137 | I_DATPAR<0> | O | I/O | OUTPUT
P138 | I_DATPAR<1> | O | I/O | OUTPUT
P139 | I_ACC<0> | O | I/O | OUTPUT
P140 | I_ACC<1> | O | I/O | OUTPUT
P141 | VCC |  | VCCINT
P142 | TIE |  | I/O
P143 | Z_NIORST | GSR | I/O/GSR
P144 | GND |  | GND
To preserve the pinout above for future design iterations in
Project Navigator simply execute the (Lock Pins) process
located under the (Implement Design) process in a toolbox named
(Optional Implementation Tools) or invoke PIN2UCF from the
command line. The location constraints will be written into your
specified UCF file

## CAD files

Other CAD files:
firmware/PCIH/isim/t_all_isim_beh.exe.sim/work/t_all_isim_beh.exe_main.nt.obj
firmware/PCIH/isim/precompiled.exe.sim/ieee/p_3620187407.nt.obj
firmware/PCIH/isim/t_all_isim_beh.exe.sim/unisim/p_0947159679.nt.obj
firmware/PCIH/isim/t_all_isim_beh.exe.sim/work/a_2474999364_2372691052.nt.obj
firmware/PCIH/isim/precompiled.exe.sim/ieee/p_1242562249.nt.obj
firmware/PCIH/isim/t_all_isim_beh.exe.sim/work/a_0537113747_3212880686.nt.obj
firmware/PCIH/isim/precompiled.exe.sim/ieee/p_3499444699.nt.obj
firmware/PCIH/isim/precompiled.exe.sim/ieee/p_2592010699.nt.obj
firmware/PCIH/isim/t_all_isim_beh.exe.sim/work/a_3490385537_3212880686.nt.obj
firmware/PCIH/isim/t_all_isim_beh.exe.sim/work/a_2380750733_3212880686.nt.obj
firmware/PCIH/isim/t_all_isim_beh.exe.sim/work/a_2995207169_3212880686.nt.obj
firmware/PCIH/isim/t_all_isim_beh.exe.sim/work/a_2259037628_3212880686.nt.obj

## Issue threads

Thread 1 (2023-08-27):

Awesome!

tkurbad, 2023-08-27:
This is something I wanted to do for a long time! Even contacted Michael Böhmer (E3B) about it.

You are the man, @shanshe!

shanshe, 2023-08-27:
This summer has been very "productive" ;)

First time I saw the new schematics and those lines, I thought that it was some kind of "new features". Also interrupt lines were swapped. Then I saw original prometheus board schematics, and I put all like the original one (but I routed 3.3V to the PCI connectors, following the new schematics).

Some components are NC in my schematics, as they are mainly for debugging. I only soldered the debug connector to see some signals with a logic analyzer. There are leds, and their respective resistors, that are not used in firmware, so I left the board without them. I also routed a PLL to multiply by 2 the 33MHz from oscillator, but it is not used at all...

And yes, 0402 resistors are very very tiny. What I do is to spread some soldering paste drops, pass the soldering tip over the pads, put the resistor over the pad, and finally apply hot with a hot air gun. And of course, I use a good microscope, hehehe. I'm still under 50 (it will change in months), but my sight is not what it was :)

Please, share those corrections (no hurry, when you are back at home), so we can improve the project.

tkurbad, 2023-08-27:
I see that our modifications are quite similar. I've also added a footprint for an SMD oscillator. Nice catch with the interrupt lines. I think that was what I meant by "address lines". :-)

I did away with all the 0402 components and replaced them by resistor arrays and 0603 and larger stuff. Also routed 3.3 V to the PCI connectors and placed a footprint for a less exotic regulator.

I see that we are of similar age. I'll be 47 in about a month. Invested in a good trinocular microscope about two years ago. One of the best things I ever bought for the hobby...

shanshe, 2023-08-27:
There was two main issues.
Addresses lines 16 to 19, has to be connected to every PCI SEL lines (A16 to the first PCI, A17 to the second,…). They were connected to other lines.
Interrupt lines INTA, B, C and D were connected but each PCI connector had a different connection. Original Prometheus has all interrupts connected to the same pins on all PCI connectors.

shanshe, 2024-03-31:
I will write here another issue that I find in the original E3B xilinx firmware.
The IO space had also a byte swap mistake. The fix was uploaded two weeks ago.

mheyer32, 2024-03-31:
What is the practical result of these byte swaps from the programmer's perspective?

shanshe, 2024-03-31:
It was a hardware issue (a xilinx CPLD firmware issue). For example, a voodoo 3 card didn't work before this was fixed, it didn't even show anything in its VGA output (with the current prometheus libraries).
Now, prometheus xilinx and altera versions are closer in their behavior, but xilinx's one seems to do things better than altera's (timing issues when writing data through PCIe bridges for example).

mheyer32, 2024-03-31:
Oh, I understand this fix makes sure, Xilinx and Altera behave the same. Well done! Looking forward the A3000/A4000 daughterboard versions!

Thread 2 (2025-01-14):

Picasso doesn't detect graphics card

oguzog, 2025-01-14:
My friend built this card but it is not working.

It is built by instructions given here and

And tested instructions given here
https://www.amibay.com/threads/basic-guide-on-setting-up-a-prometheus-firebird-daughterboard-on-a3000-and-a4000-now-here-on-amibay.2446084/

We can see prometheus on whichamiga and also voodoo 3 itself but we cannot get graphics from Picasso.
Even tried newest libraries, drivers but same. tried on both 3.2 roms and 3.2 OS and 3.9 roms on 3.9 OS.

Same result

prmscan detects something but Picasso doesn't detect anything.
Tried both voodoo 3 3000 and s3 virge
(both cards tried on a1200 mediator without any poblem)

Also thought maybe something went wrong on build and we built a new one.
Same results.

See screenshots

Maybe system doesn't find RAM for DMA. Added DMASIZE=2048K to the info as seen on screenshots

Any suggestions?

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

oguzog, 2025-01-18:
Issue solved when i use SMD type oscillator instead of the old style one.

Closed 2025-01-18.

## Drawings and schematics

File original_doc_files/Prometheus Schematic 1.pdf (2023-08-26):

# Prometheus Amiga PCI Bridge by Grzegorz Kraszewski for Matay, 2001

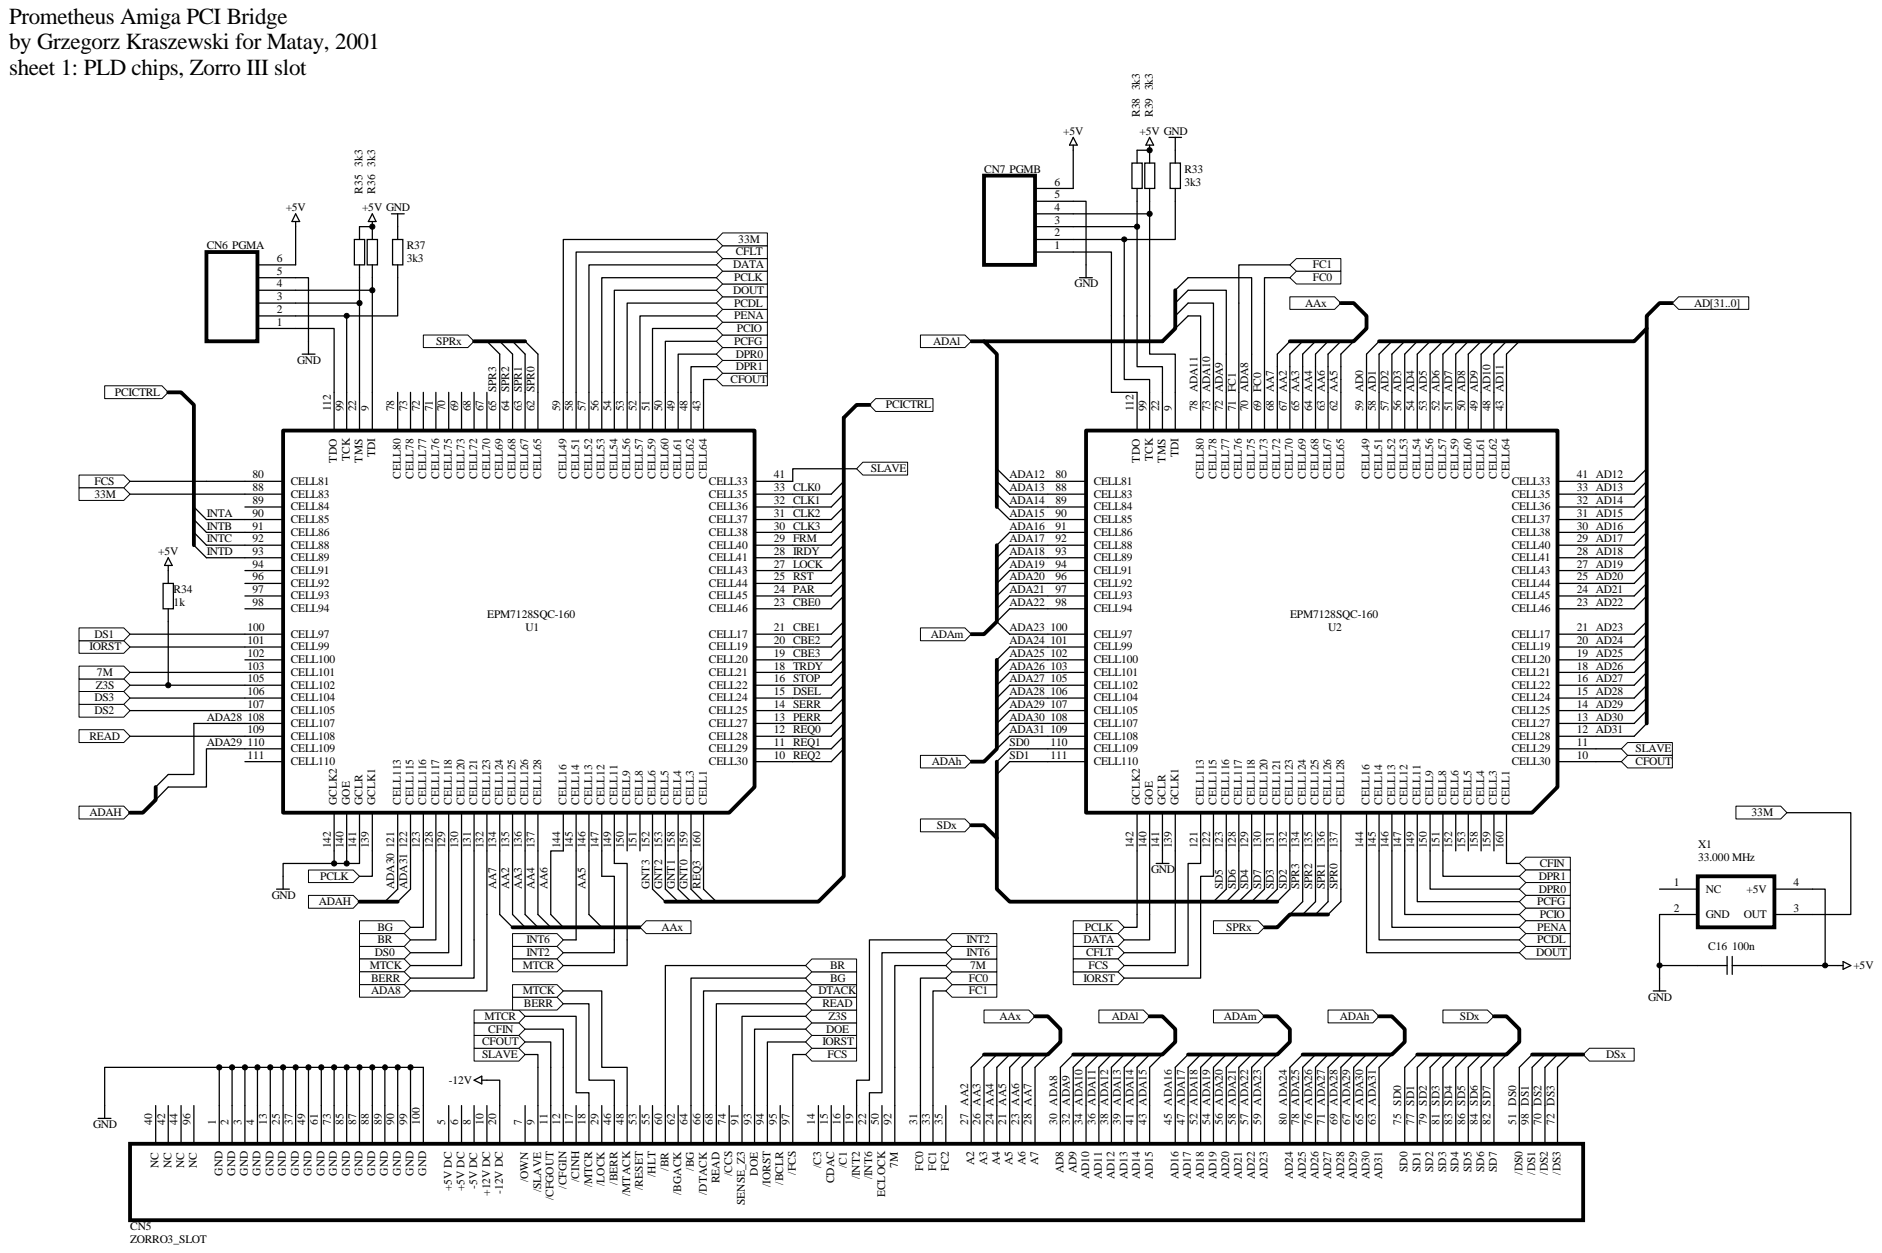
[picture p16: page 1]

sheet 1: PLD chips, Zorro III slot

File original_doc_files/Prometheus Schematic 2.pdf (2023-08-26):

# Prometheus Amiga PCI Bridge by Grzegorz Kraszewski for Matay, 2001

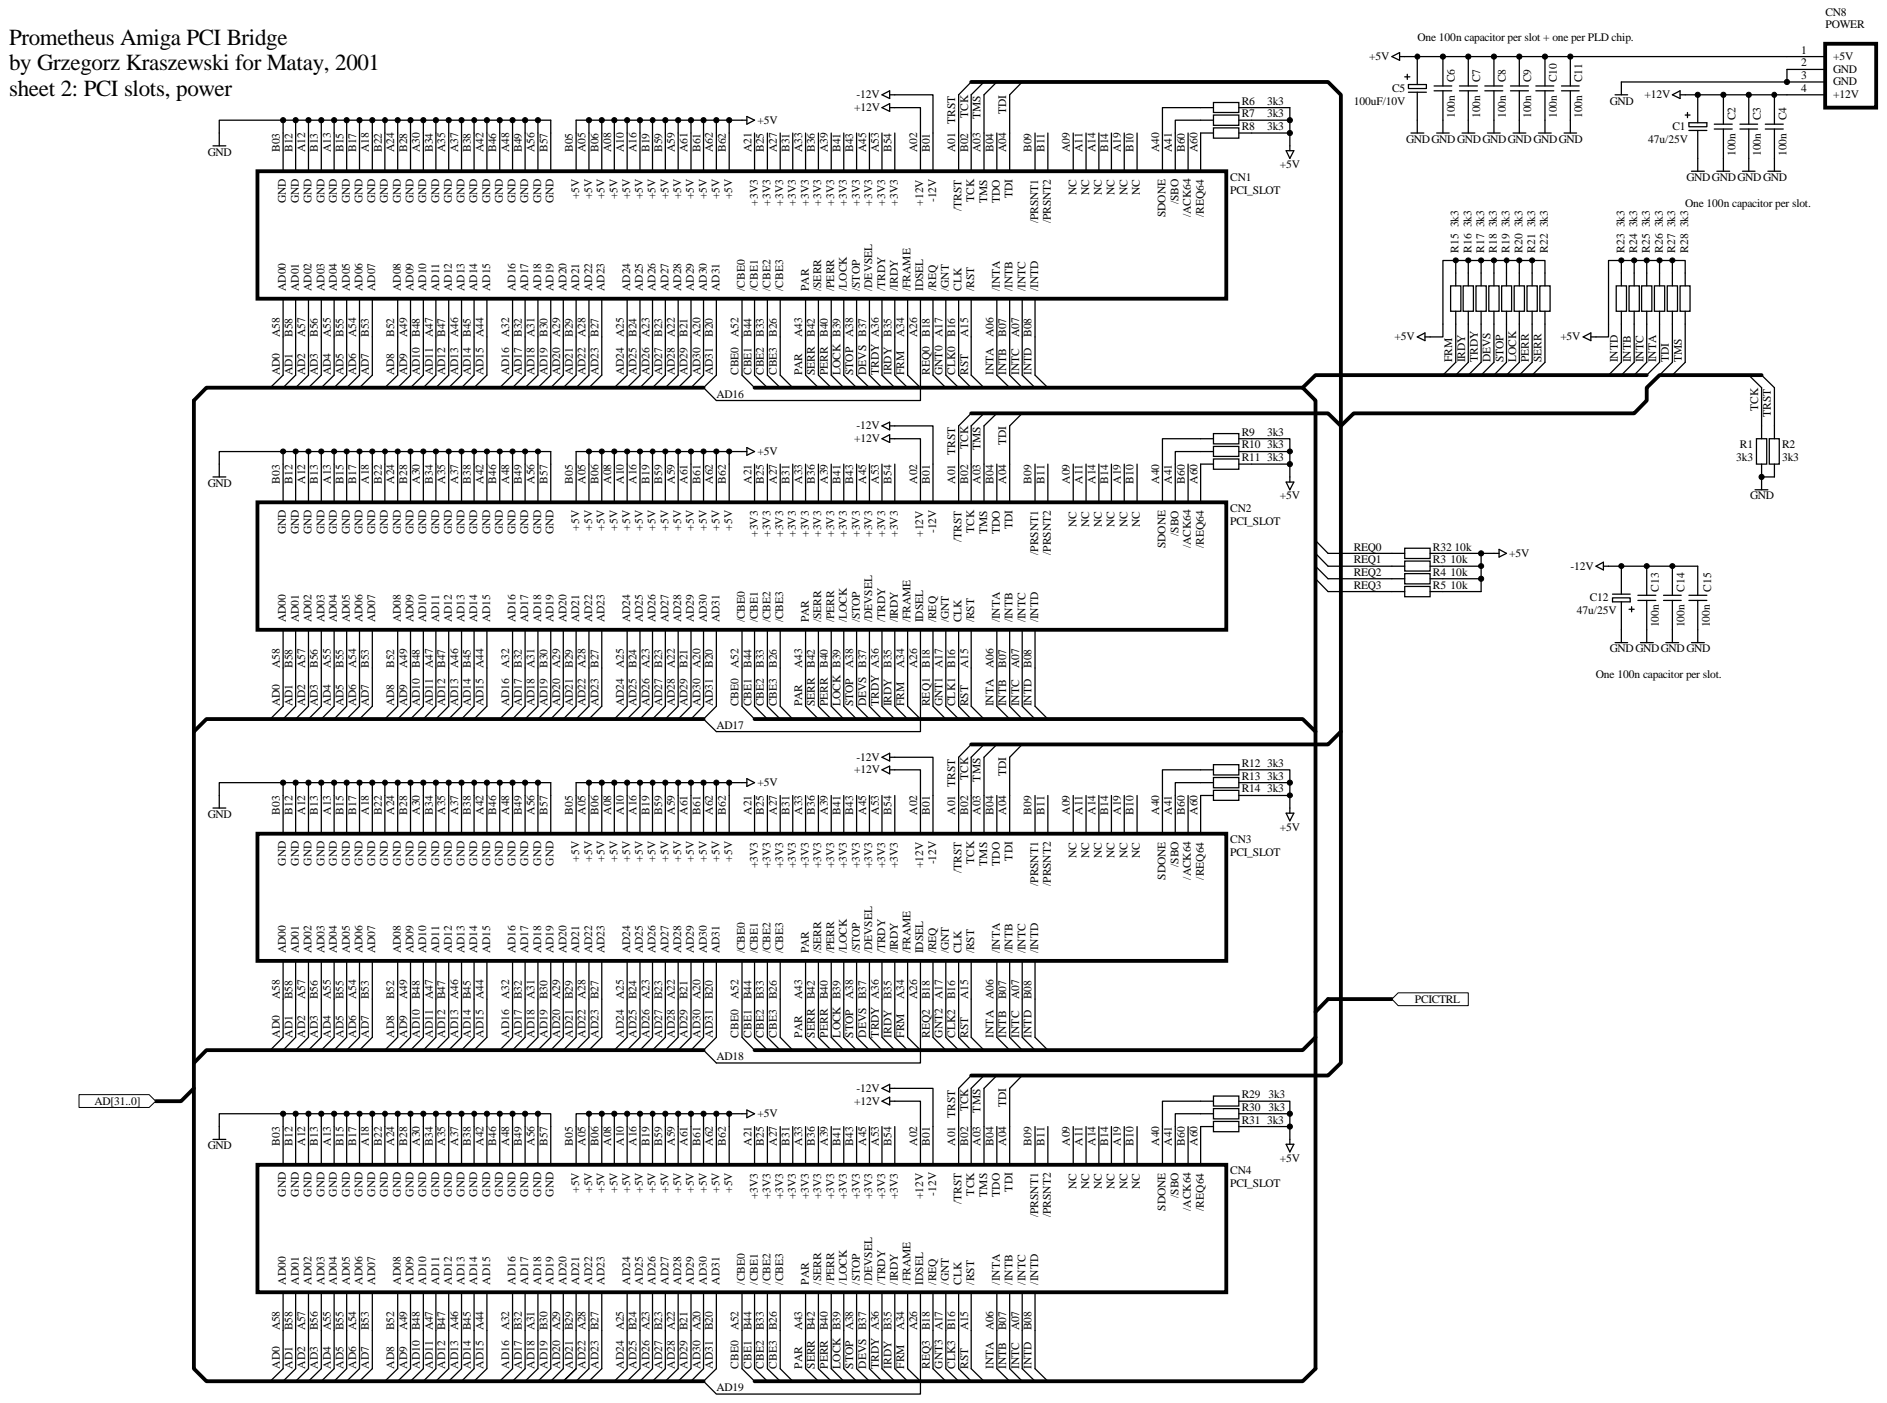
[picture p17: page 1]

One 100n capacitor per slot + one per PLD chip.

sheet 2: PCI slots, power

One 100n capacitor per slot.

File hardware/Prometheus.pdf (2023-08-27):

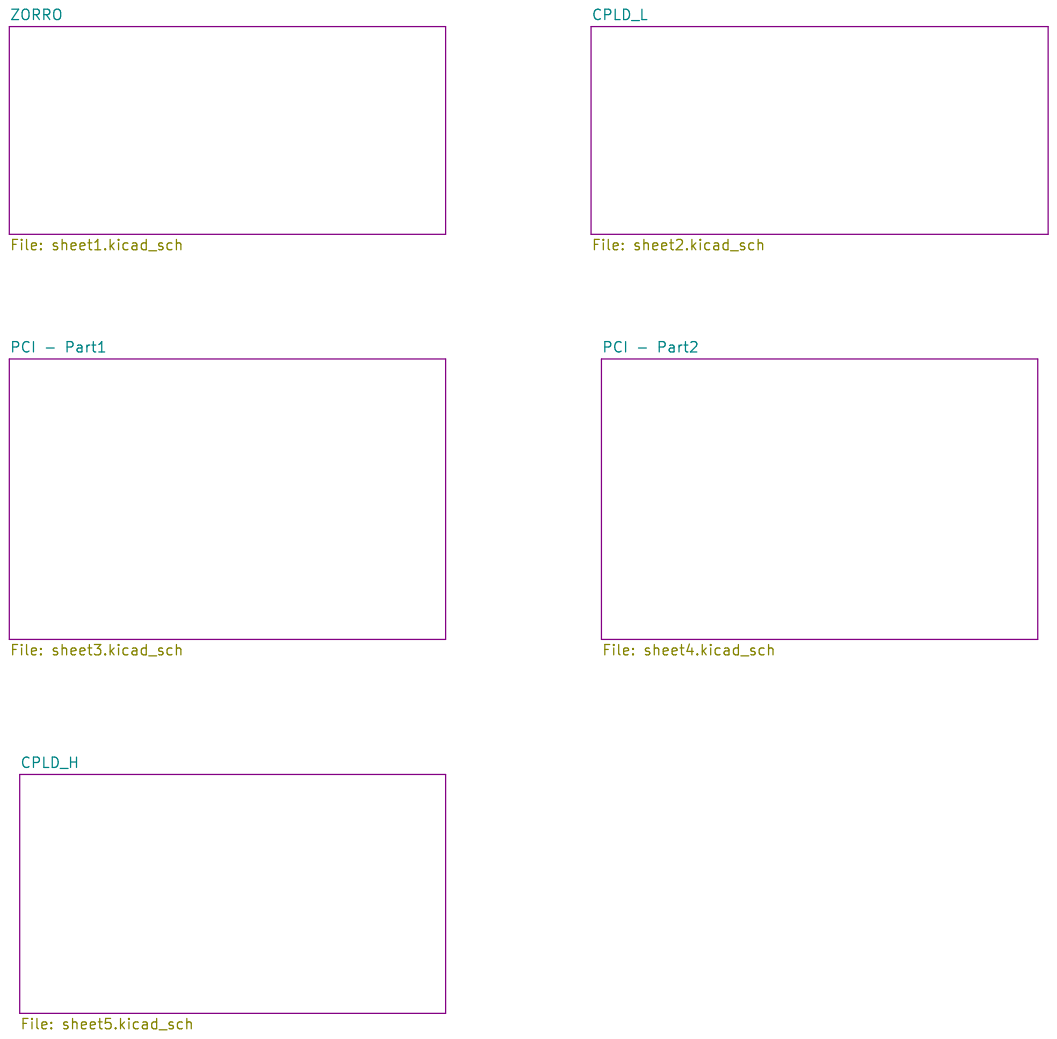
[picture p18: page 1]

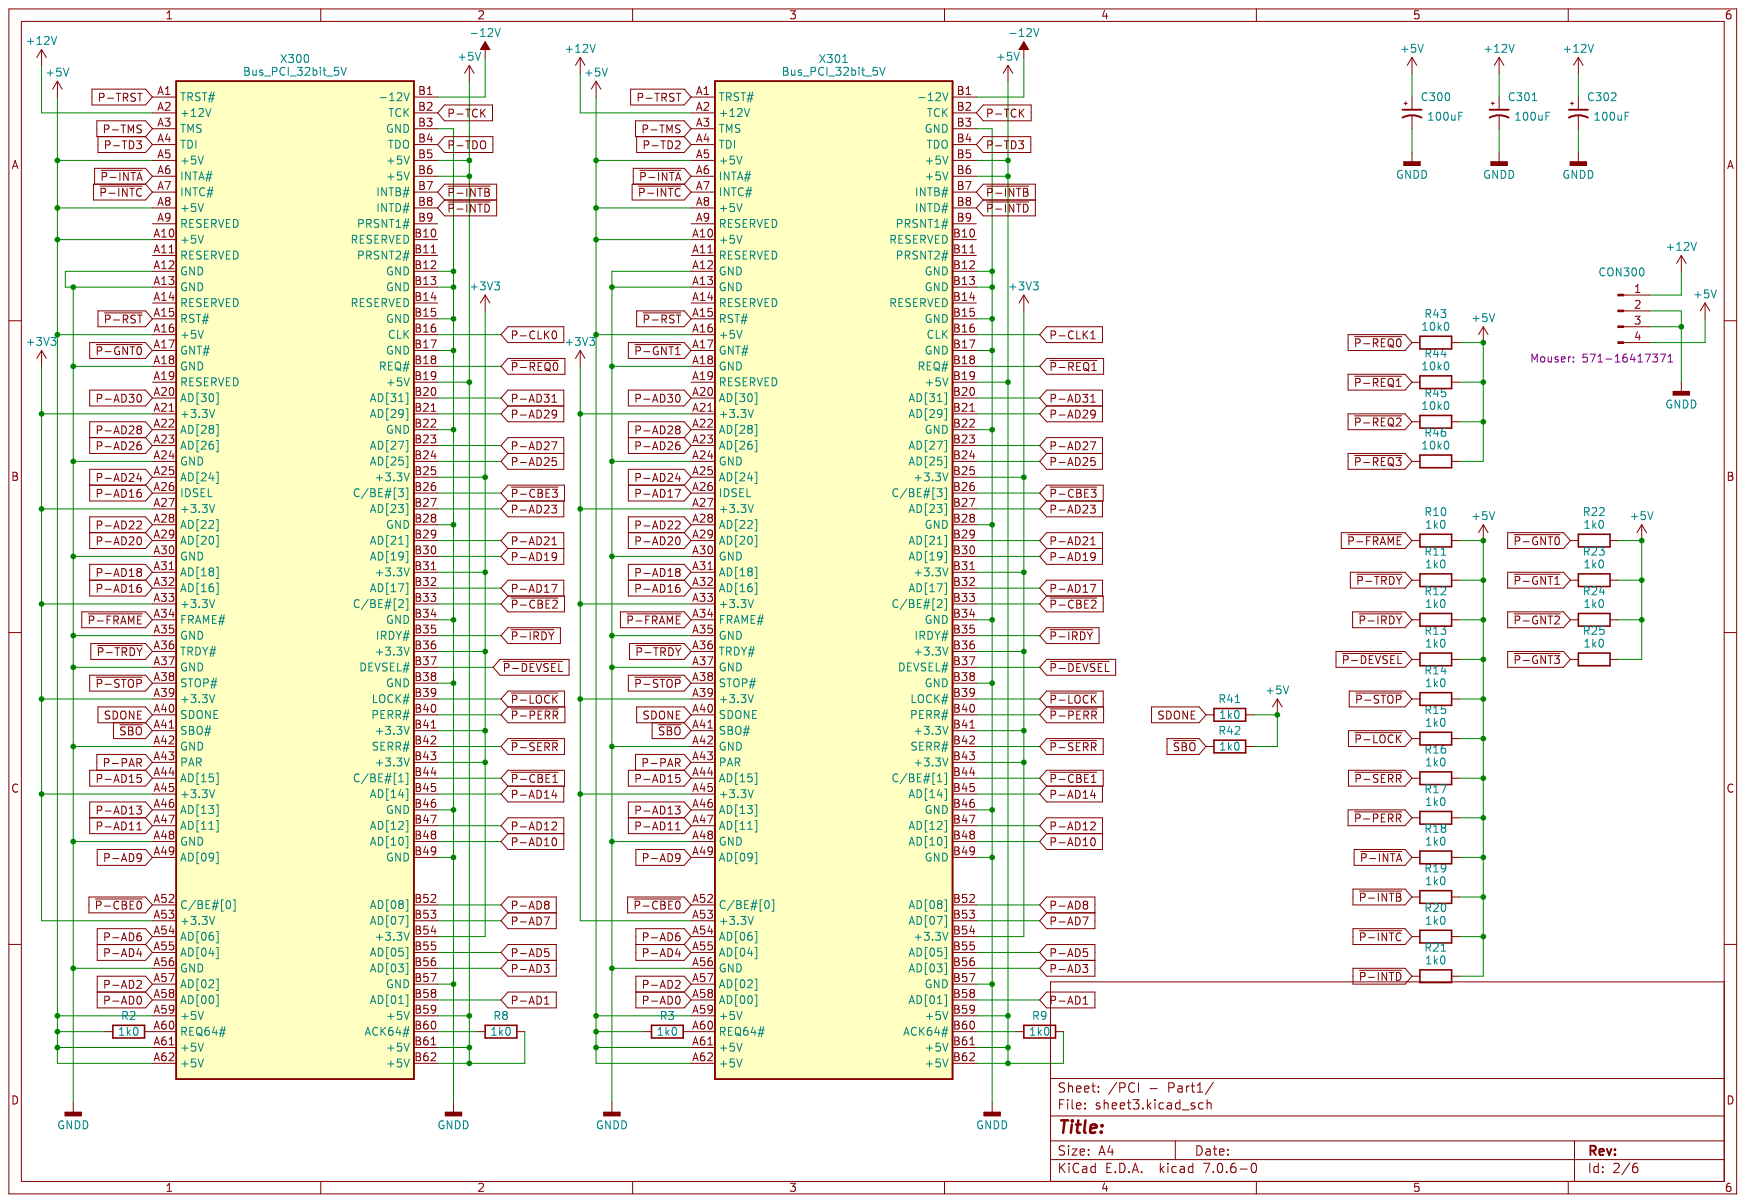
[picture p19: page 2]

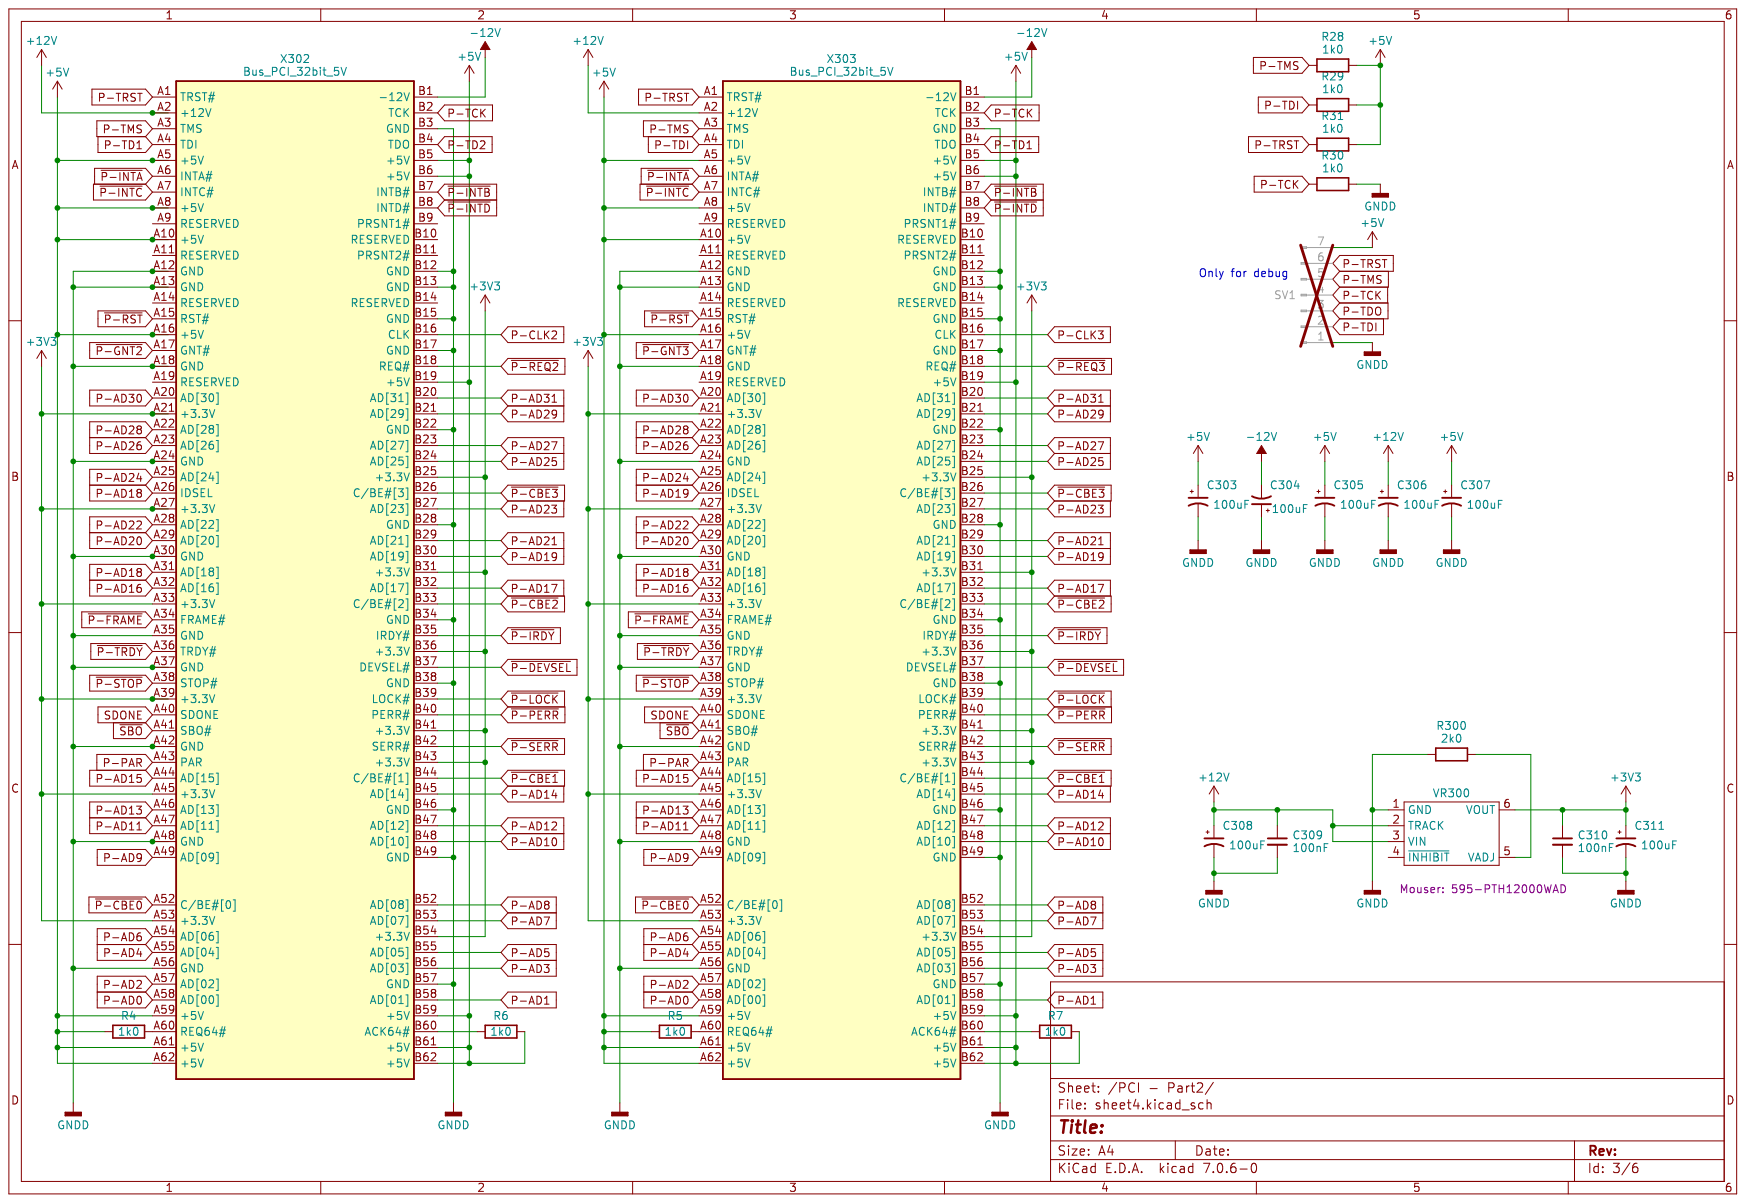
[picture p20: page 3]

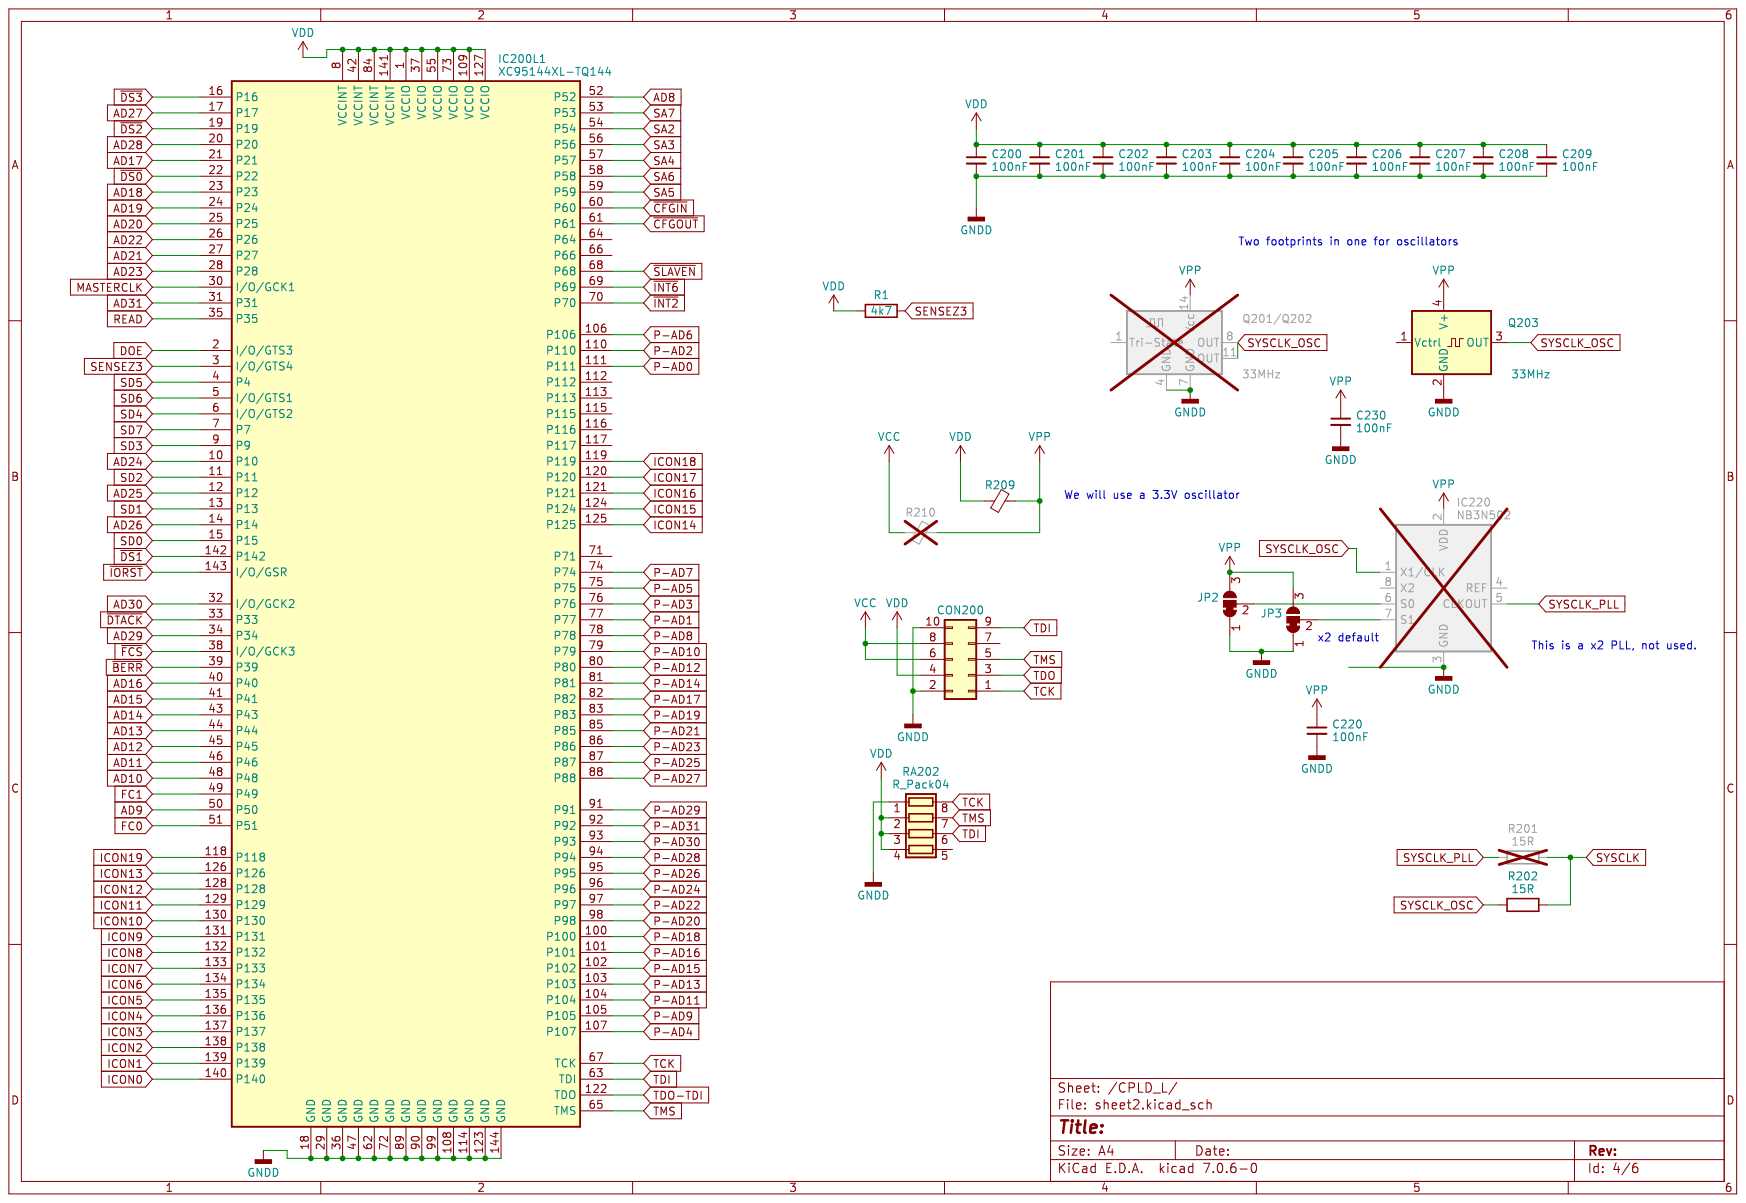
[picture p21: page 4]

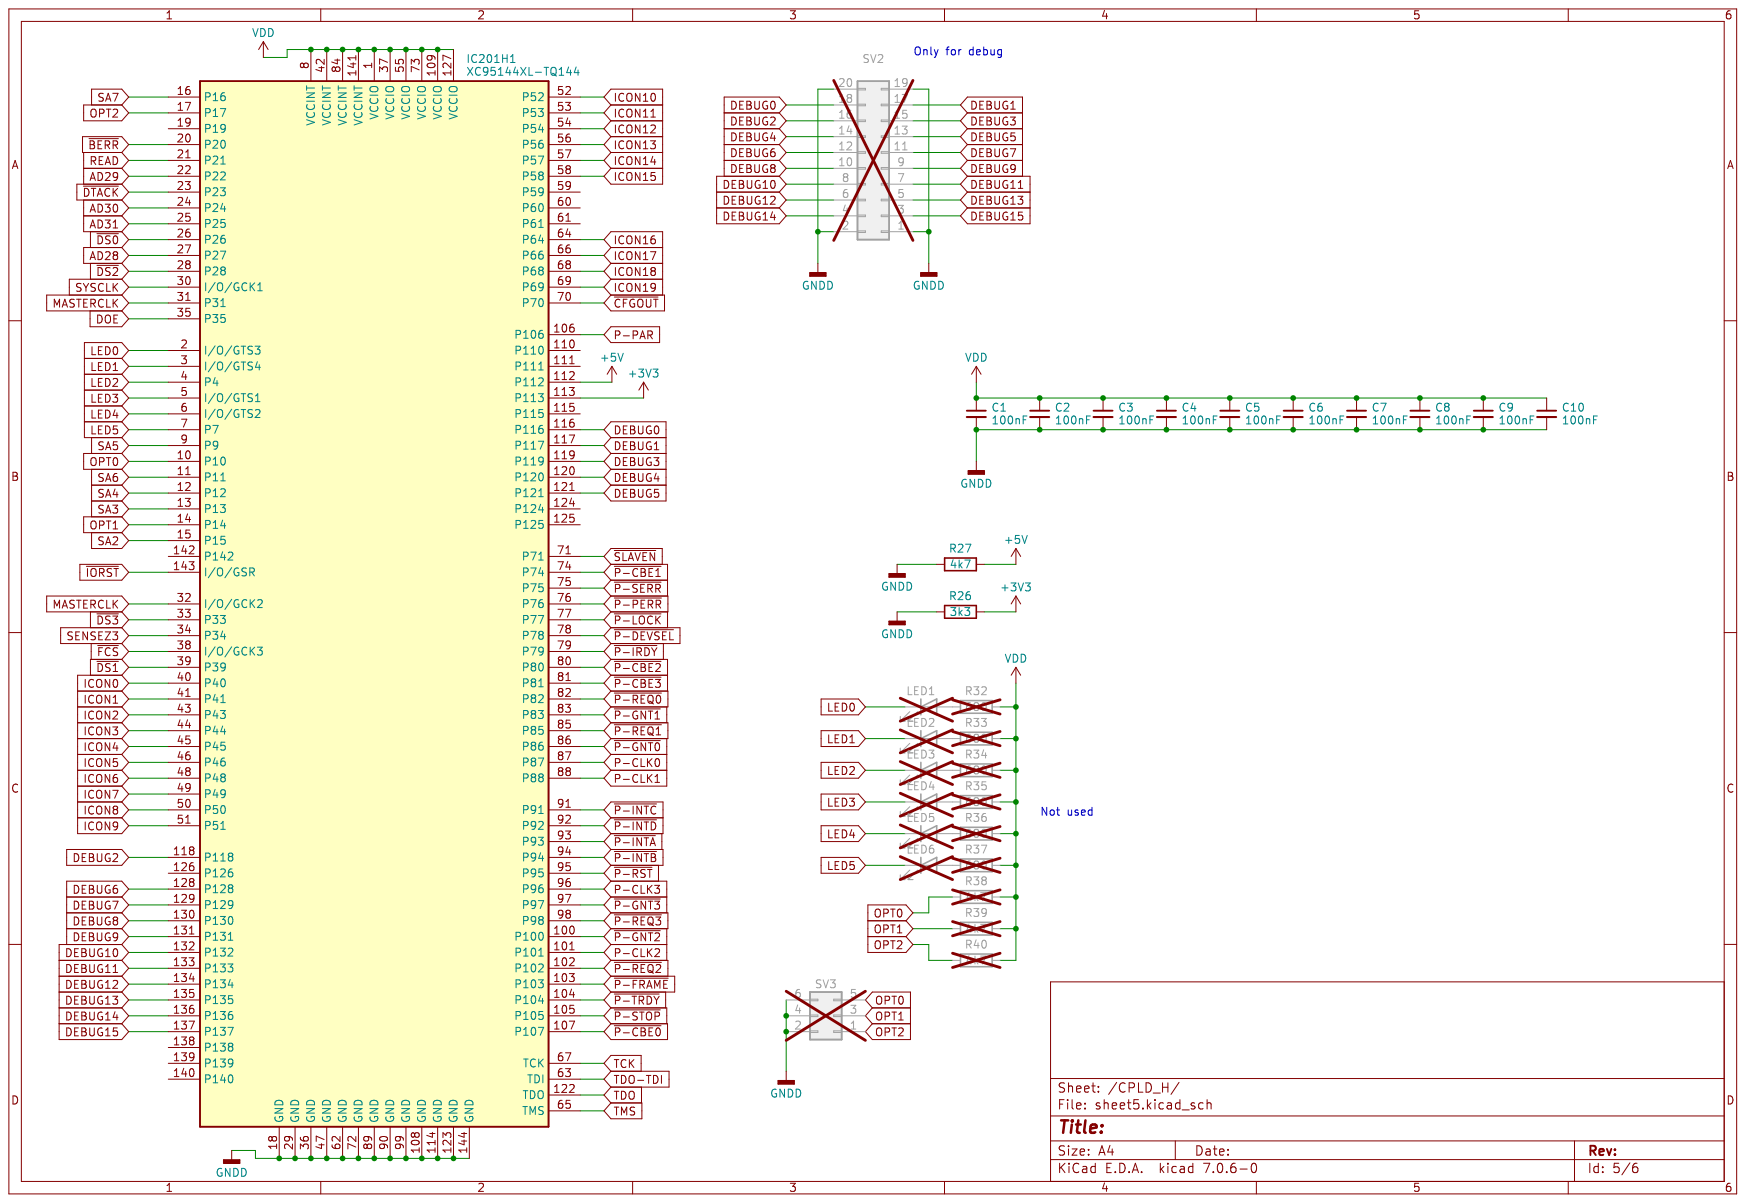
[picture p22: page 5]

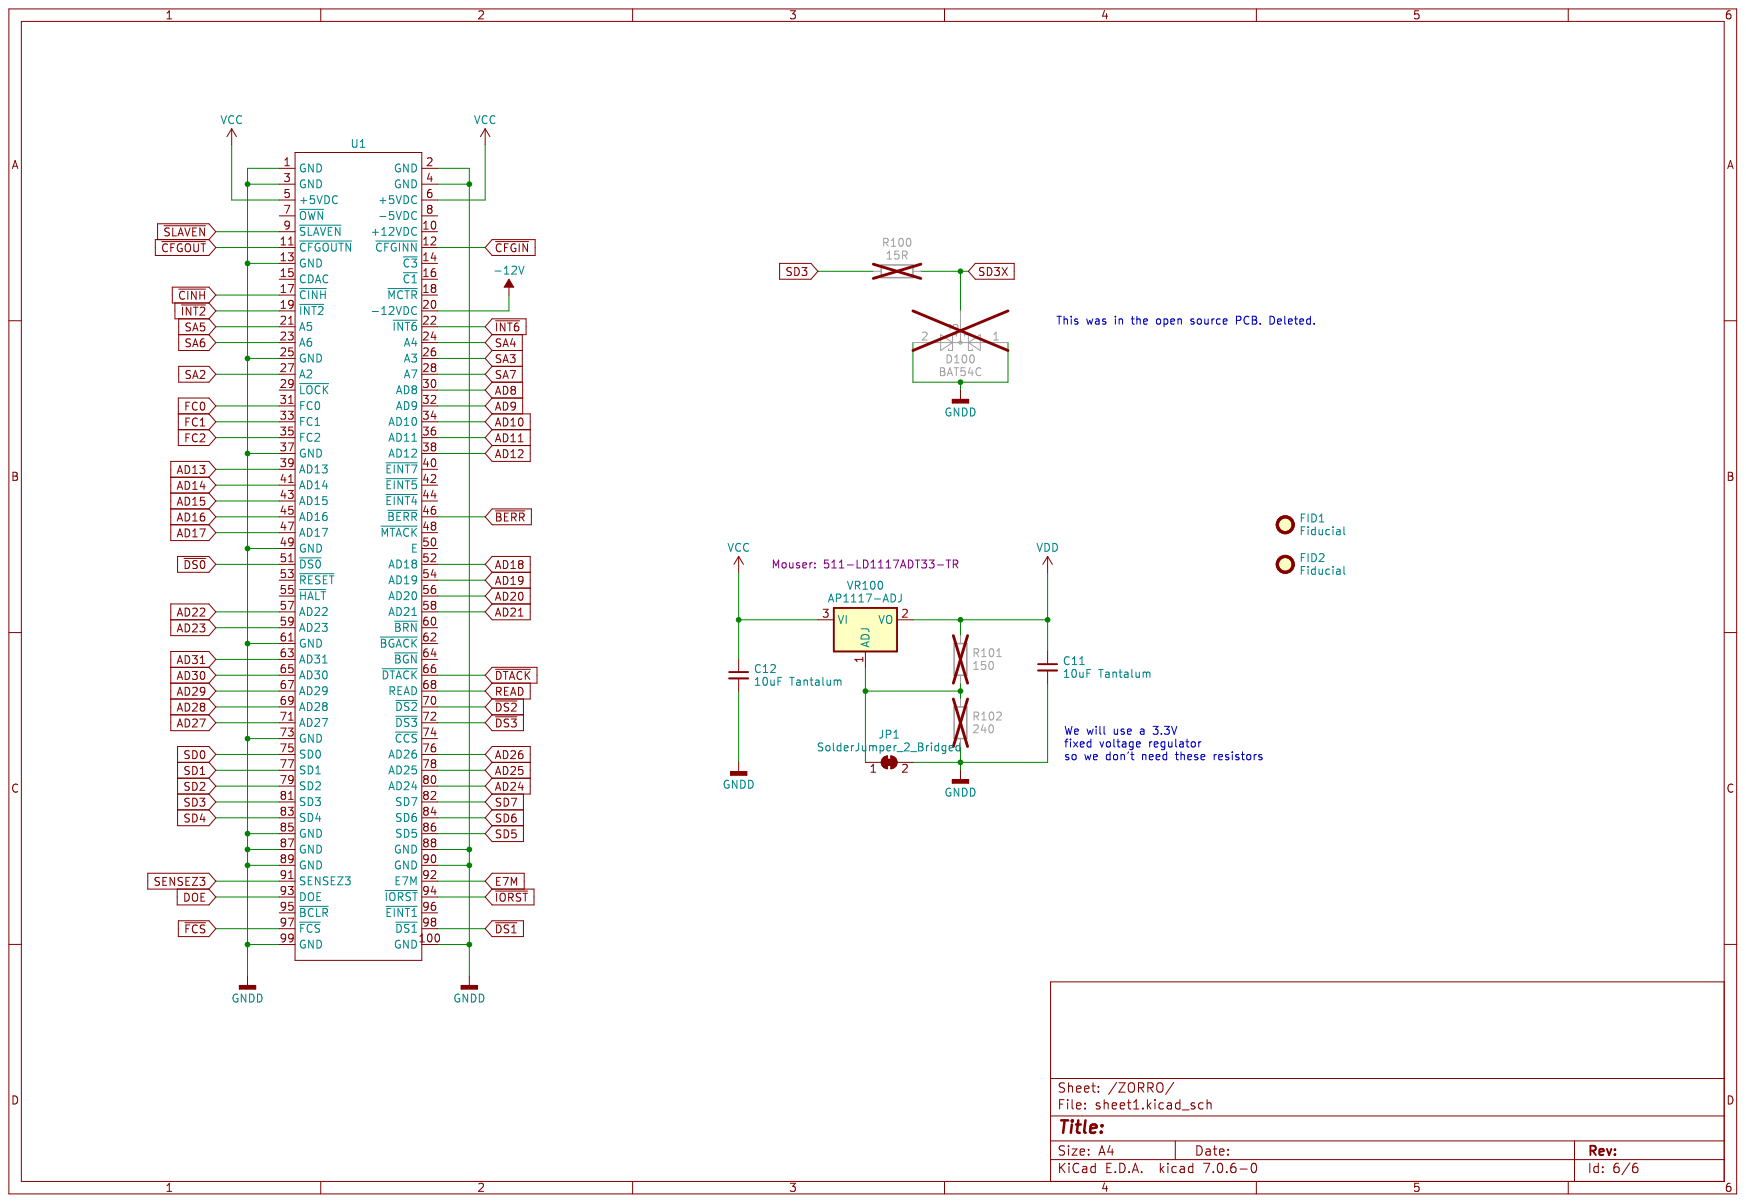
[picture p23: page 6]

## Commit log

2023-08-26 Upload hardware (fabrication and source) files
    [Prometheus-B_Cu.gbr, Prometheus-B_Mask.gbr, Prometheus-B_Paste.gbr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]
2023-08-27 Add schematics in pdf format
2024-03-15 Updated CPLD HI to work with voodoo
    [a_0537113747_3212880686.nt.obj, a_2259037628_3212880686.nt.obj, a_2380750733_3212880686.nt.obj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]
2024-06-24 Tidy up the PCI arbiter, and hopefully, fix SLOT1 PPC hang
2024-06-24 upload of all project files
    [pcih_pad.csv, pcil_pad.csv]
